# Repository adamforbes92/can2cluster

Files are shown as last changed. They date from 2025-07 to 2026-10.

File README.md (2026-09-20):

# Can2Cluster
Can2Cluster is designed to take CAN messages and convert them into an analog output for use on clusters with traditional pull-down style inputs.  It is geared towards VAG CAN messages but Ford and Emerald ECUs CAN IDs have been added too.

The code is based for an ESP32 DevKit V1, and will capture incoming CAN messages and convert them into useable 'analog' signals - like RPM, Speed, Engine Management Light (EML), Electronic Pedal Control Light (EPC) and Reverse (from DSG).  A full breakdown is below.  

Alternative setups and CAN IDs can be added and would allow custom features.

DSG gearboxes are supported and speed is currently calculated using the current gear value and RPM.  KWP2000 / UDS has been implemented and awaits testing!

On MQB vehicles, pressing the DSG Paddle +/- inputs is relayed onto the CAN bus as the real shifter/paddle module's own frame (`0x0AF`), reverse-engineered directly from a live shifter capture rather than a generic aftermarket emulation - so it lands on the bus exactly as the factory paddles would.

If no speed is available (from either hall or CAN), an optional GPS module (like the Neo6M) can be used to capture speed via. GPS.  This can be broadcast via. CAN if required - users should know the ID they would like it broadcast to.  A reminder that GPS modules need to see the sky and depending on installation location may need an external aerial to be fitted.  It uses a standard SMA connector.

WiFi calibration is supported to minimise code editting and provides valueable feedback on incoming messages.  It is viewable on 192.168.1.1 and is available for 60 seconds after boot.  If no devices connect, the WiFi will power-down automatically to reduce power consumption and heat generated by the unit.

**There is a difference in pin-out between Version 1 and Version 2 PCBs - although functionality is the same.  Confirm pinouts using the 'Module Pinout' table.**

This can be expanded to support other marques and is actively encouraged.  Other users are actively using the DSG support and using the EML/EPC outputs to configure shift locks and other features.

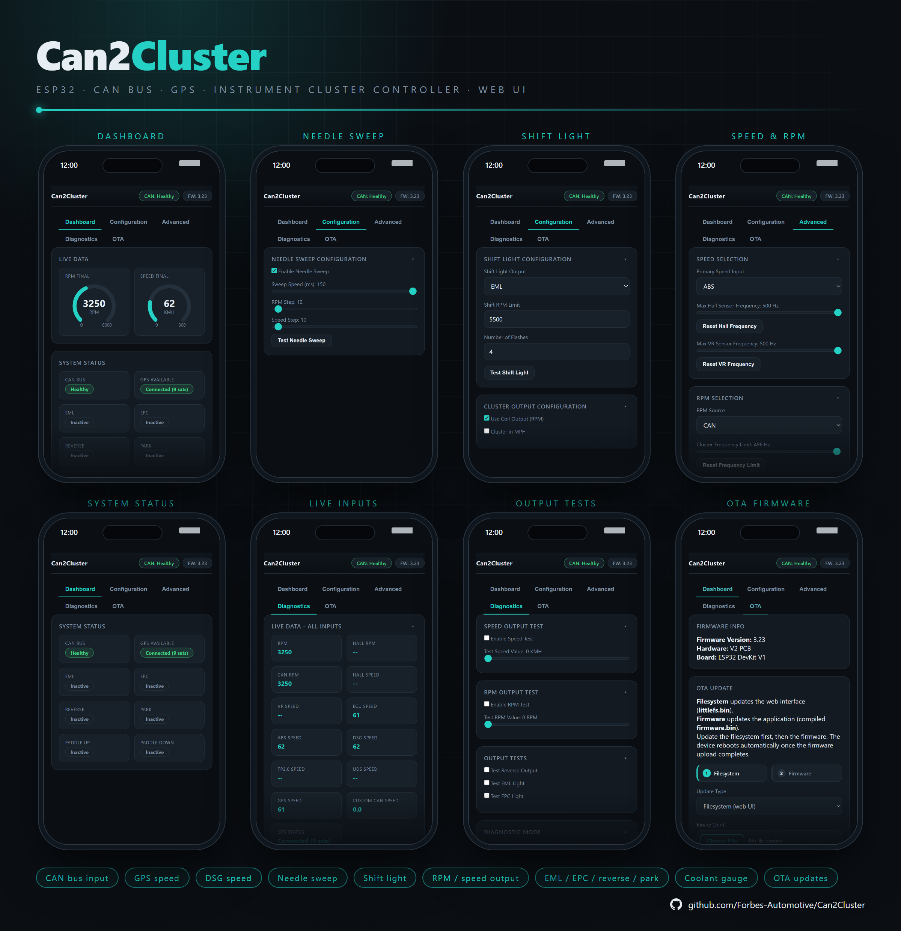
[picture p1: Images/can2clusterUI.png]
Can2Cluster Web UI — dashboard, needle sweep, shift light, speed & RPM sources, status, live inputs, output tests and OTA


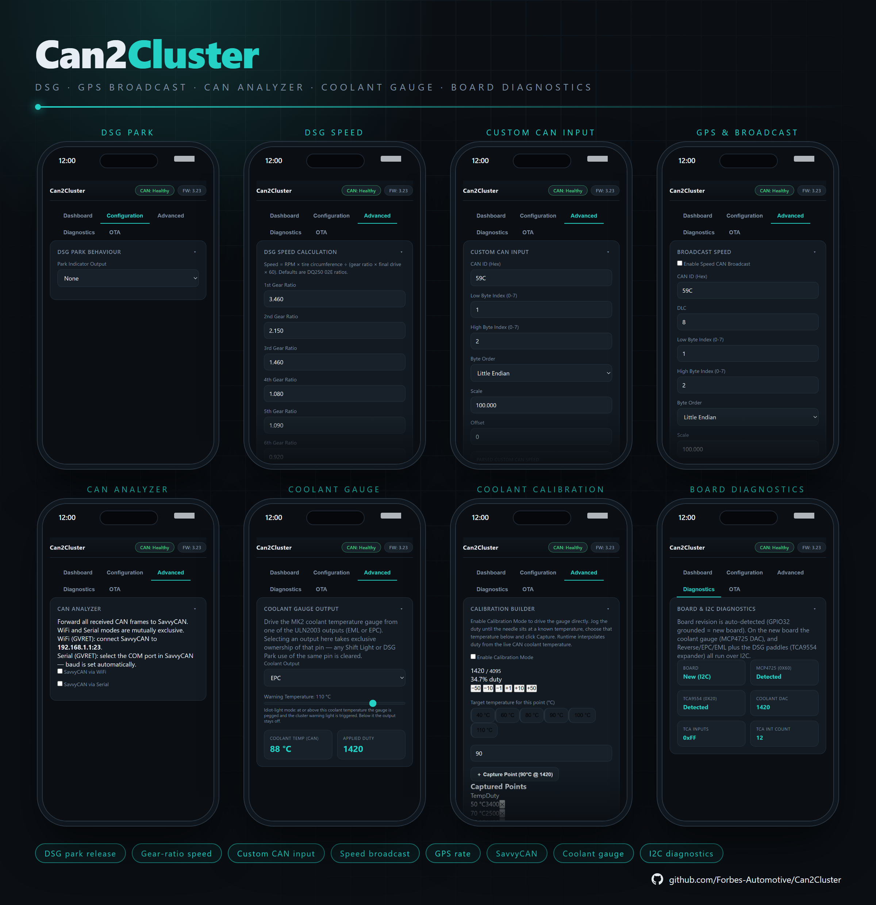
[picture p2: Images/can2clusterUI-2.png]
Can2Cluster Web UI — DSG park and speed calculation, custom CAN input, GPS & speed broadcast, CAN analyzer, coolant gauge and board diagnostics


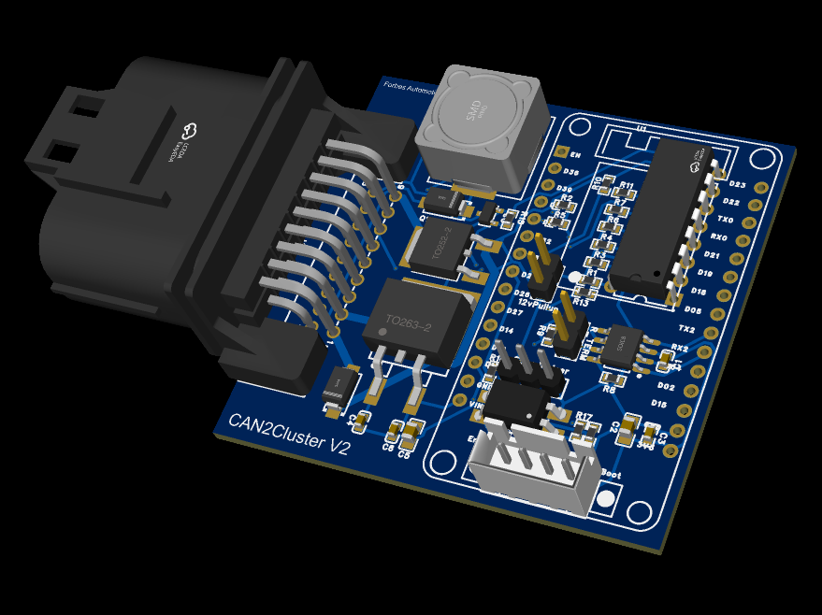
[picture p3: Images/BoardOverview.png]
Board Overview


### Purchase
If you want to purchase an assembled Can2Cluster, you can do so here: [Can2Cluster - Forbes Automotive](https://forbes-automotive.com/products/can2cluster)

## IO
Can2Cluster uses an 18-pin MX23A18 connector and features the following IO:

#### IO List
| Type | Signal | Notes |
|-----|---|---|
| Input | CAN (High & Low) | CANBUS |
| Input | DSG Paddle + | Ground to activate |
| Input | DSG Paddle - | Ground to activate |
| Input | Hall Speed | Pull-up/down options |
| Input | Hall RPM | Pull-down ONLY |
| Input | GPS | Neo6M or similar |
| Output | RPM (MK1/MK2) | High voltage 'coil type' |
| Output | RPM Square | Pull-down ONLY |
| Output | Speed Square | Pull-down ONLY |
| Output | EML & EPC | Pull-down ONLY |
| 11 | Reverse | 5A high-side |

#### Optional / Cool Features 
Shift Light (RPM vs. EML/EPC)
Needle Sweep
Park release for DSG

### Pinout
The MX23A18 connector pinout is:
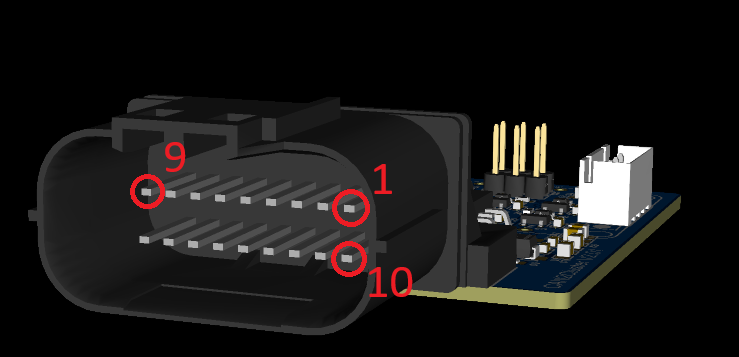
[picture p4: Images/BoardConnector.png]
Board Overview


| Pin/ | Signal | Notes |
|-----|---|---|
| 1 | Vign | 12V Ignition |
| 2 | Ground | Chassis ground — |
| 3 | Chassis CAN Low | to Chassis/ECU side |
| 4 | Chassis CAN High | to Chassis/ECU side |
| 5 | Speed | Speed output; pull-down |
| 6 | RPM | RPM output; pull-down |
| 7 | EML | Engine Management Light; pull-down |
| 8 | EPC | Electronic Pedal Control Light; pull-down |
| 9 | Reverse | 12v high-side reverse output; 5A max |
| 10 | Paddle Up | For DSG; pull-down |
| 11 | Paddle Down | For DSG; pull-down |
| 12 | Hall Speed | Optional pull-up/down |
| 13 | N/A | Not used |
| 14 | N/A | Not used |
| 15 | N/A | Not used |
| 16 | N/A | Not used |
| 17 | N/A | Not used |
| 18 | RPM | High voltage coil pulse; MK1/MK2 etc |

> **Legacy clusters & needle jitter:** On some older cluster, the coil-style RPM output can induce a little jitter in the hall inputs due to poor grounding. Fitting a **~500 Ω resistor in series** with the RPM output largely reduces this.

## Setup
Purchased modules will come pre-loaded with the most recent firmware, check back here for updates.  

> Connect the module as per the wiring diagram

> On initial power up, WiFi is available and will remain active while any client is connected. Once the last client disconnects, the radio turns off automatically after 1 minute to save power (see Power Management below).

> Connect to the device and search for '192.168.1.1' in a browser

> Configure the device to suit: Needle Sweep, Sweep Rate, RPM Type, Shift Light

> Use the 'IO' tab to confirm incoming data

### WiFi Setup
Connect to the **`Can2Cluster`** access point (open network, `192.168.1.1`) and browse to **192.168.1.1** or **c2c.local**. The Web UI is built on Forbes Automotive's shared dark theme, the same look used across OpenHaldex, SpeedPulser, SpeedPulserPro, can2rpm, the MQB Steering Wheel Controller and AirLift Controller. Current firmware version: **3.23**.

Multiple options are available in WiFi:
> Needle Sweep (rate adjustable)

> RPM Output Selection

> Shift light outputs (EML/EPC or both)

> Park Lock Release (for DSG)

> Speed Selection (Hall/ECU/ABS/DSG/GPS)

<p align="center">
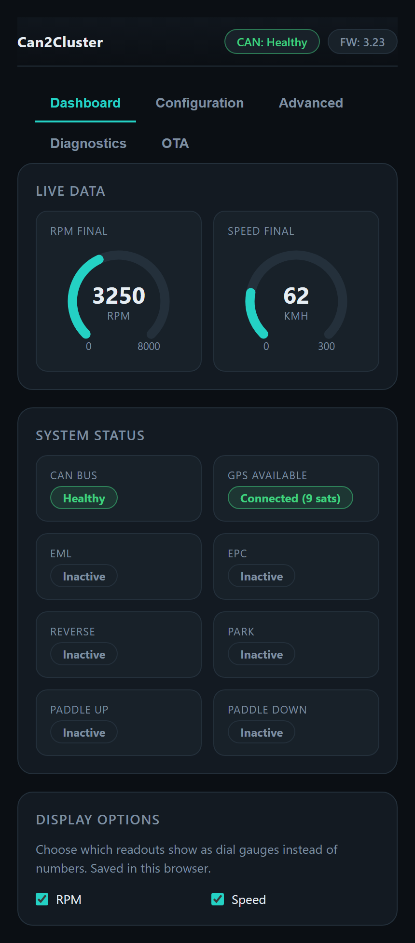
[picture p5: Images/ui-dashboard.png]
Dashboard — RPM and speed gauges, system status pills and display options
  
  &nbsp;&nbsp;
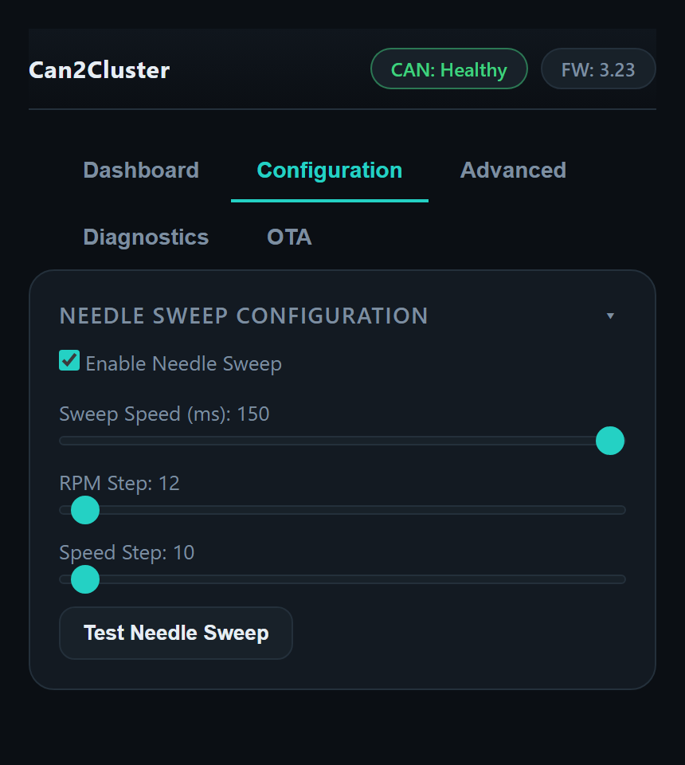
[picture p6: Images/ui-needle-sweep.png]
Configuration — needle sweep enable, sweep speed and RPM / speed step
  
</p>
<p align="center">
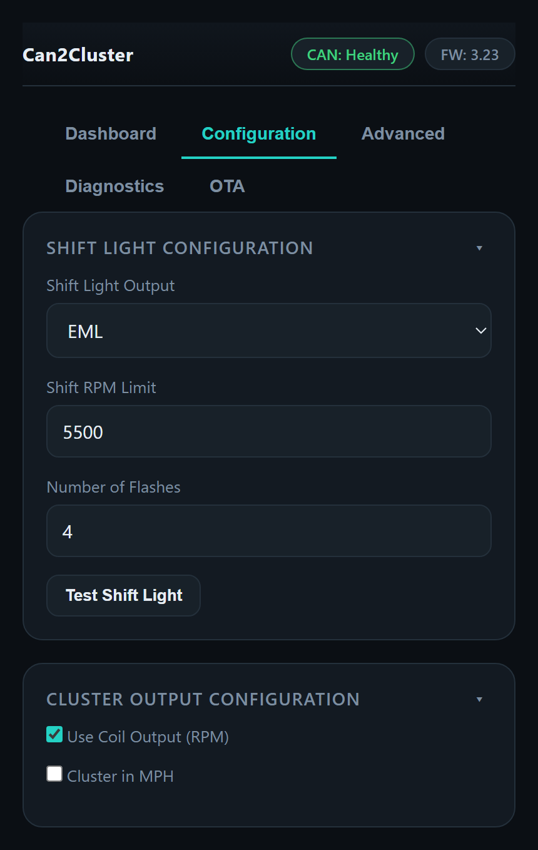
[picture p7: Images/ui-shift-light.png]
Configuration — shift light output, RPM limit and flashes; cluster output coil / MPH options
  
  &nbsp;&nbsp;
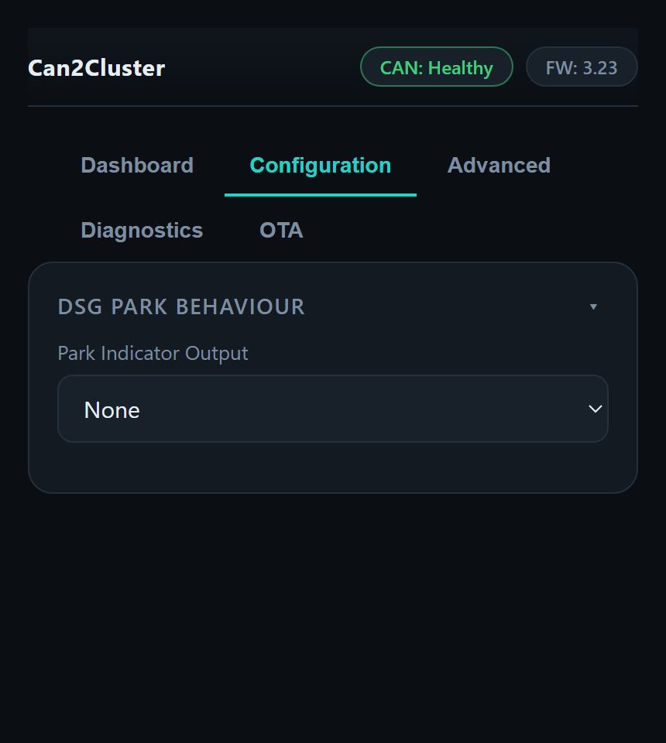
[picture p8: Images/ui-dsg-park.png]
Configuration — DSG park behaviour (park indicator output)
  
</p>
<p align="center">
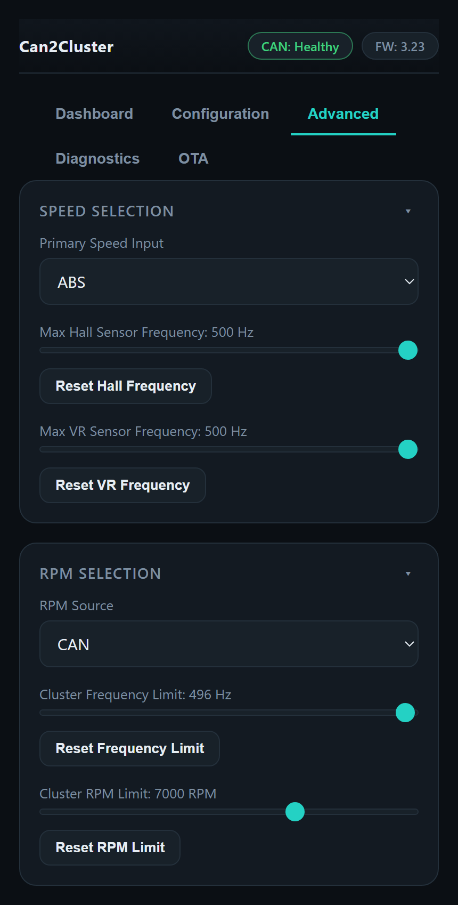
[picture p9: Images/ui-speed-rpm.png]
Advanced — speed and RPM source selection with hall / VR frequency limits
  
  &nbsp;&nbsp;
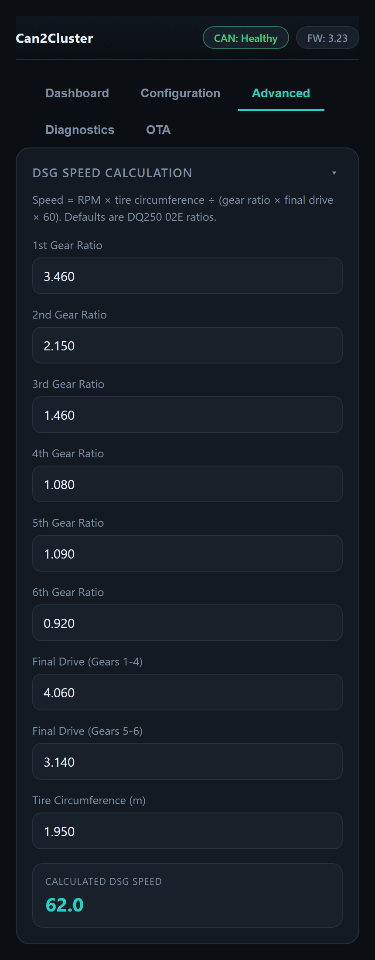
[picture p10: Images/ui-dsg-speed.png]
Advanced — DSG speed calculation: gear ratios, final drives and tyre circumference
  
</p>

*Dashboard with the final RPM/speed as dial gauges and the status pills; needle sweep, shift light, cluster output and DSG park release on the Configuration tab; speed and RPM source selection under Advanced. Choosing **DSG** as the speed source reveals the gear-ratio calculator (speed = RPM × tyre circumference ÷ gear ratio × final drive).*

**Status indicators:** CAN health, GPS and output (EML/EPC/Reverse) status are shown as coloured pills in the Web UI:

| Colour | Meaning |
|---|---|
| 🟢 Green | Healthy / active — CAN bus is healthy, GPS has a satellite lock, or the output reflects a real vehicle CAN signal |
| 🔴 Red | Unhealthy / not available — CAN bus unhealthy, or no GPS module fitted/connected |
| 🟠 Orange | A caveat, not a failure — GPS module is connected but has no satellite fix yet ("Connected (no sats)"), or an EML/EPC/Reverse output is being **forced on via the built-in test/diagnostic mode** rather than a real vehicle signal |

<p align="center">
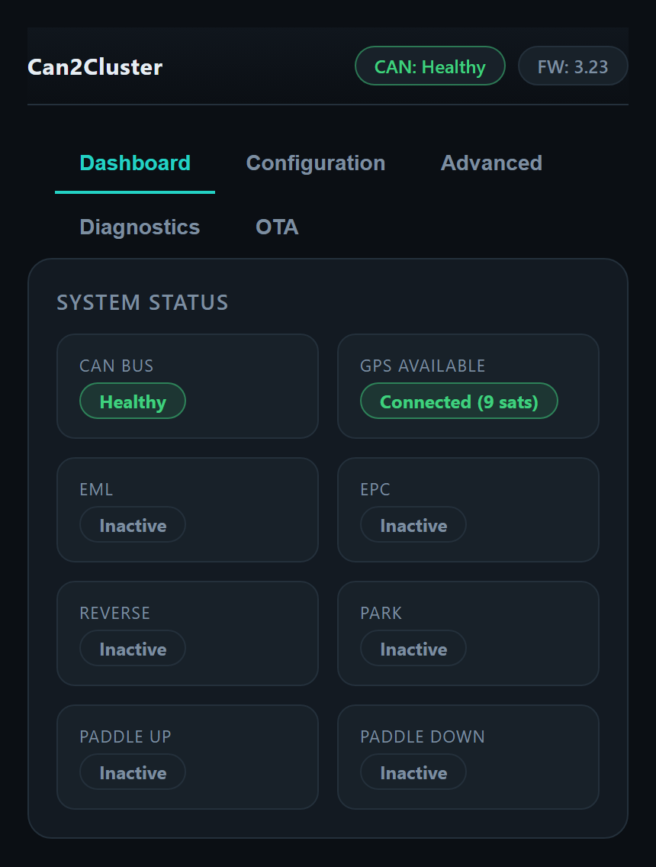
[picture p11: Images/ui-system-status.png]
Dashboard — system status pills: CAN bus, GPS, EML, EPC, reverse, park, paddles
  
</p>

## Adding CAN Functionality
Users wishing to add CAN functionality not available are encourged to push commits to the project.  The main section of code for managing imcoming CAN messages are handled in an interrupt and corresponding outputs are pushed automatically.  Users should know the CAN ID and Bytes they wish to process and what variables to assign them to.

Two things in the Web UI help here. **CAN Analyzer** (Advanced tab) forwards every received frame to [SavvyCAN](https://www.savvycan.com/) over WiFi (GVRET, `192.168.1.1:23`) or over the USB serial port, so you can find the ID and bytes you're after. And for a speed signal on a non-standard ID, **Custom CAN Input** (choose *Custom* as the speed source) lets you enter the CAN ID, byte positions, byte order, scale and offset without touching the code:

<p align="center">
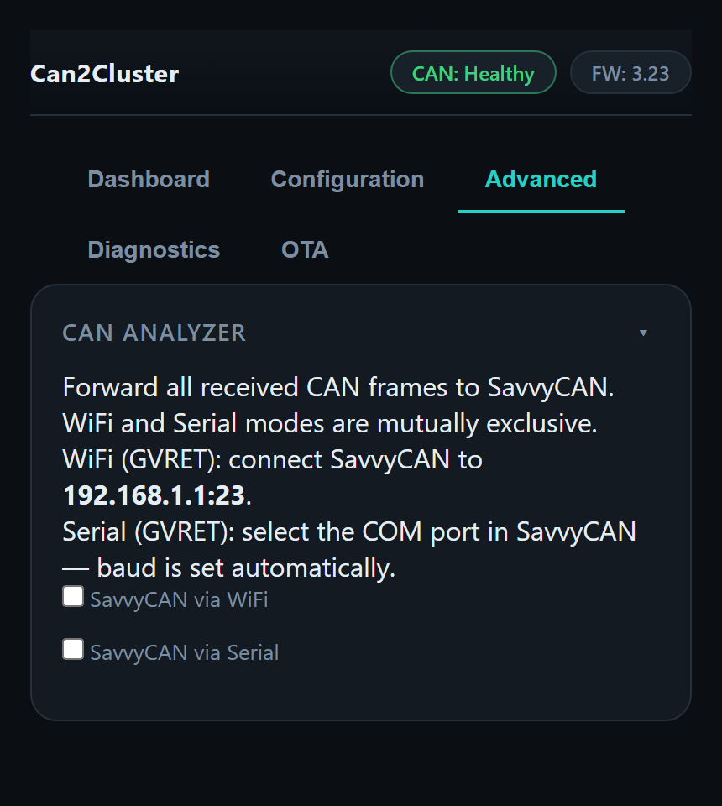
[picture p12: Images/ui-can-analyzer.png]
Advanced — CAN Analyzer: forward frames to SavvyCAN over WiFi or serial
  
  &nbsp;&nbsp;
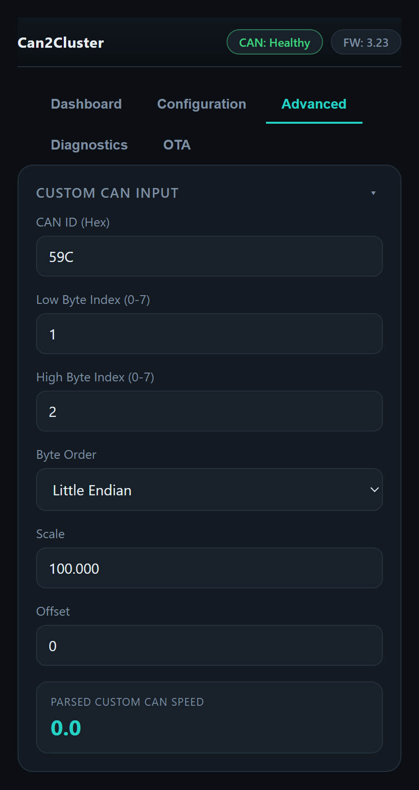
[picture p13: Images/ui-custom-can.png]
Advanced — Custom CAN Input: CAN ID, byte indexes, byte order, scale and offset, with the parsed speed shown live
  
</p>

For example (in _CAN.ino under "onBodyRX");
```
    case emeraldECU1_ID:
      vehicleRPM = ((frame.buf[0] << 8) | frame.buf[1]);  // conversion: 0.25*HEX // this is RPM
      break;

    case emeraldECU2_ID:
      vehicleSpeed = ((frame.buf[2] << 8) | frame.buf[3]) * (2.25 / 256);  // conversion: 0.25*HEX // this is RPM
      break;

```
The above entry will check to see if there is a CAN message from "0x1000" or "0x1001" (Emerald ECU 1 & 2) and then parse the data to the relevant variables.

## Adding GPS
Users wishing to add GPS at a future date can do - the boards are already socketed in readiness.  The 4-pin JST XH Connector will provide 3.3v, RX, TX and ground.

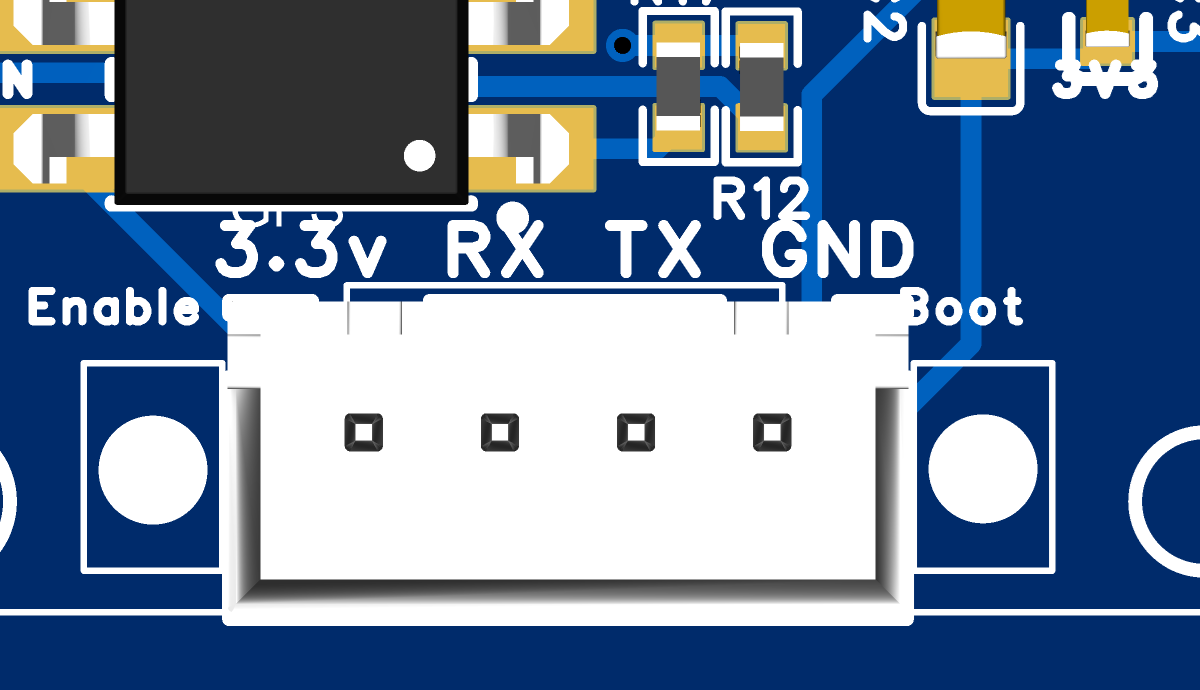
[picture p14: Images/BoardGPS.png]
GPS Connection


Once fitted, pick **GPS** as the speed source on the Advanced tab. The same tab sets the receiver's **update rate** and, if another module on the bus needs the speed, **Broadcast Speed** puts it onto CAN on an ID, byte layout and scale of your choosing:

<p align="center">
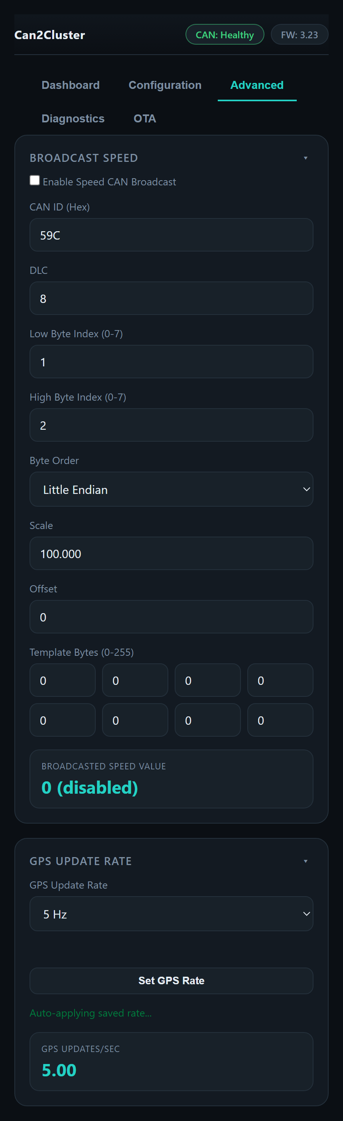
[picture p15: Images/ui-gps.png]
Advanced — Broadcast Speed (CAN ID, DLC, byte layout, scale) and GPS Update Rate
  
</p>

## Hall & RPM Input Parsing
When speed or RPM is taken from the hall/VR/pulse inputs (rather than CAN), the frequency is measured within a **windowed capture** rather than a single edge-to-edge period. Each interrupt accumulates the edge intervals and a count, and the task averages them once per loop (`frequency = intervals ÷ summed interval time`) — which gives a true average over a period.

This matters because a single-period reading turns tone-wheel / tooth-spacing jitter straight into a jumpy needle. Pulses that are arriving closer than ~3 ms (> 333 Hz) are rejected as electrical noise, so electrical or ignition-coil EMI on the input can't be mistaken for a valid speed or RPM. The averaged frequency is then mapped to the cluster scale (`map(frequency, 0, maxFreqHall/maxRPM, 0, maxSpeed/clusterRPMLimit)`).

Every input the module can see is listed side by side on the **Diagnostics** tab, so it is obvious which sources are live before choosing one, and the output tests drive the cluster directly from the page:

<p align="center">
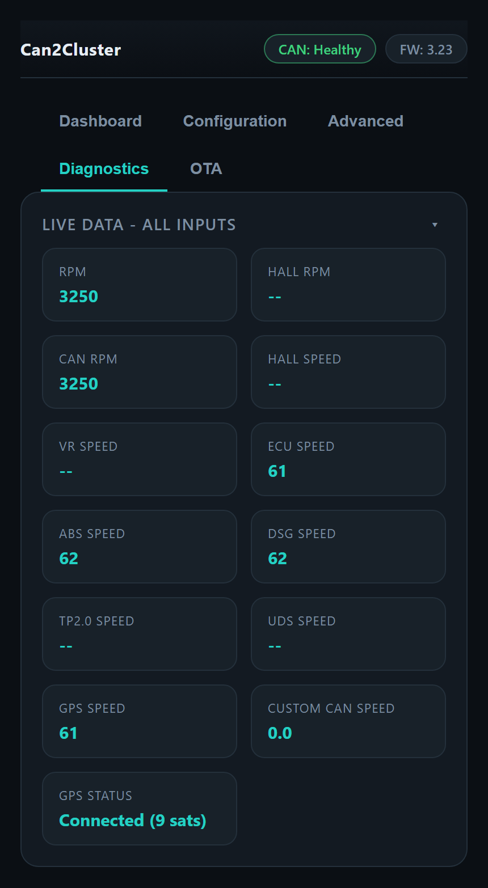
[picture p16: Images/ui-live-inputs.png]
Diagnostics — live data from every input: RPM, hall, CAN, VR, ECU, ABS, DSG, TP2.0, UDS, GPS and custom CAN speed
  
  &nbsp;&nbsp;
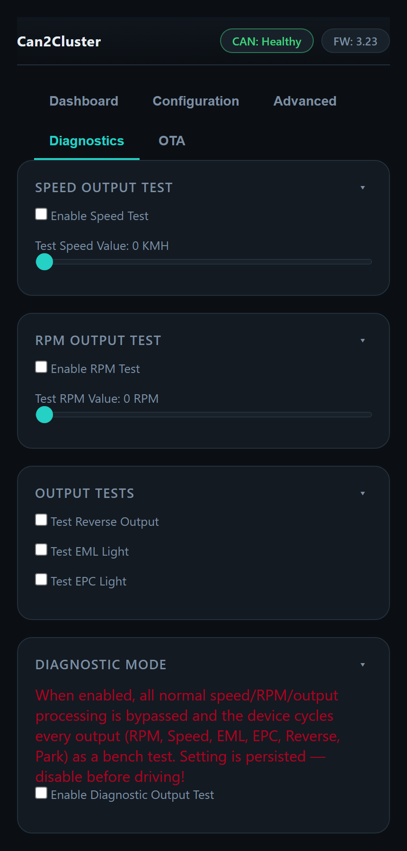
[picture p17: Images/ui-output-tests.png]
Diagnostics — speed and RPM output tests, EML / EPC / reverse output tests and diagnostic mode
  
</p>

*Diagnostics: every speed and RPM source side by side (left); slider-driven speed and RPM output tests, the EML / EPC / reverse output tests and the diagnostic (forced-output) mode that shows as orange pills on the dashboard (right).*

The Diagnostics tab also reports which board revision was detected and whether the I2C peripherals on the V2 PCB (the coolant DAC and the port expander that drives Reverse / EPC / EML and reads the DSG paddles) answered:

<p align="center">
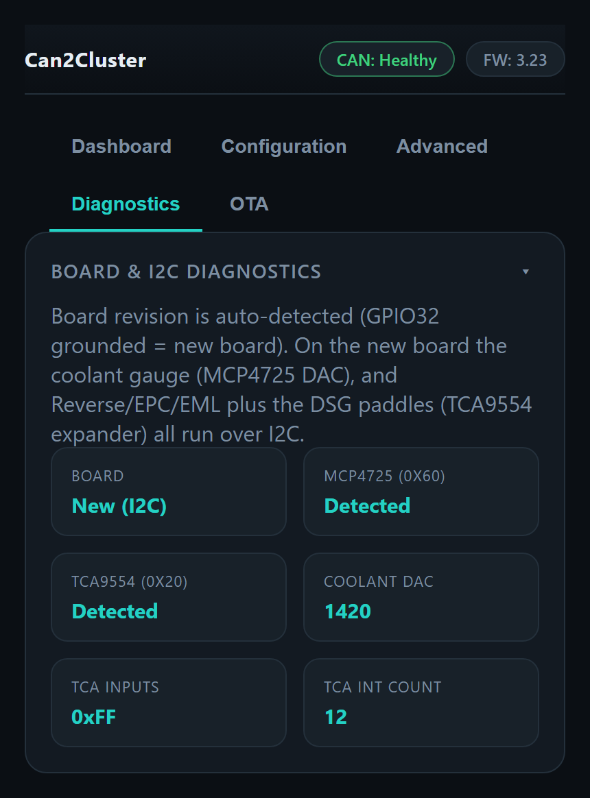
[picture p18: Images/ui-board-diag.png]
Diagnostics — Board & I2C diagnostics: board revision, MCP4725 DAC, TCA9554 expander, coolant DAC value
  
</p>

## Coolant Gauge Output
On the V2 PCB the MK2-style coolant temperature gauge can be driven from the CAN coolant temperature through one of the ULN2003 outputs (EML or EPC — selecting one takes that pin away from the shift light / DSG park use). Above the **warning temperature** the gauge is pegged and the cluster warning light is triggered.

Because every gauge is different, the **Calibration Builder** lets you drive the needle directly: enable calibration mode, jog the duty until the needle sits on a known mark, pick that temperature and **Capture**. The stored points are drawn as a curve and interpolated at runtime.

<p align="center">
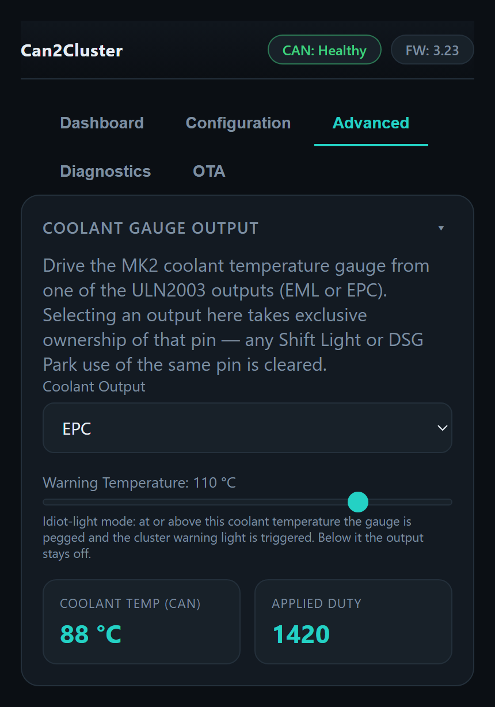
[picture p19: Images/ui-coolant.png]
Advanced — Coolant Gauge Output: output pin, warning temperature, live coolant temperature and applied duty
  
  &nbsp;&nbsp;
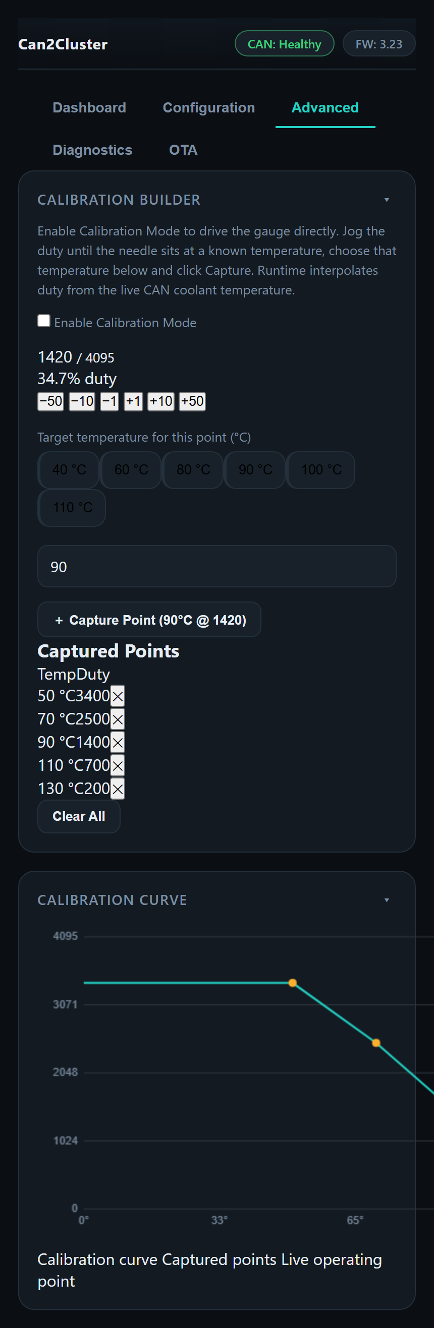
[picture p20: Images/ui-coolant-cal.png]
Advanced — Calibration Builder with duty jog buttons, captured points and the resulting calibration curve
  
</p>

## Jumpers
To keep functionality, there are a variety of jumpers available on the board which can be added/removed to suit the chassis.

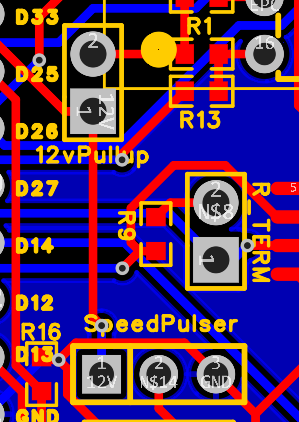
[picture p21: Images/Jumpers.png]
Jumpers


### R-Term
The jumper marked 'r-term' is the terminating resistor for the CANBUS network.  If there are no other CAN devices on the network (this is the only one), the jumper should remain.  If there are other devices on the network, this can be removed.

### SpeedPulser
A selector for a hall sensor can be configured as pull-up or pull-down with the central pin being the hall sensor itself.  Typically, VAG ones are 'pull-up'.

### 12v Pullup
Used to configure outputs if the cluster does not have internal pull-ups.

### Over-the-Air Updates (Two-Step)
OTA is enabled, so updating to the latest release is seamless and doesn't require removing the module from the vehicle. Firmware and the web UI live on separate flash partitions, so an update is done in **two steps** from the OTA tab:

1. **Filesystem** — upload `littlefs.bin` (`POST /api/ota/fs`, written to the SPIFFS partition). Updates the web UI (`index.html`, `app.js`, `style.css`). The device does **not** reboot after this step.
2. **Firmware** — upload `firmware.bin` (`POST /api/ota`, written to the OTA app partition). Updates the application and reboots automatically once complete.

`GET /api/ota/info` reports the running version, board and hardware.

> Download the most recent 'Release' - this will be saved locally on your phone/laptop/etc as `.bin` file(s)

> Connect to Can2Cluster on WiFi (or browse to c2c.local)

> Go to 192.168.1.1 and choose the OTA tab

> Upload the filesystem image first, then the firmware image

> Wait for the ESP to reboot after the firmware step

<p align="center">
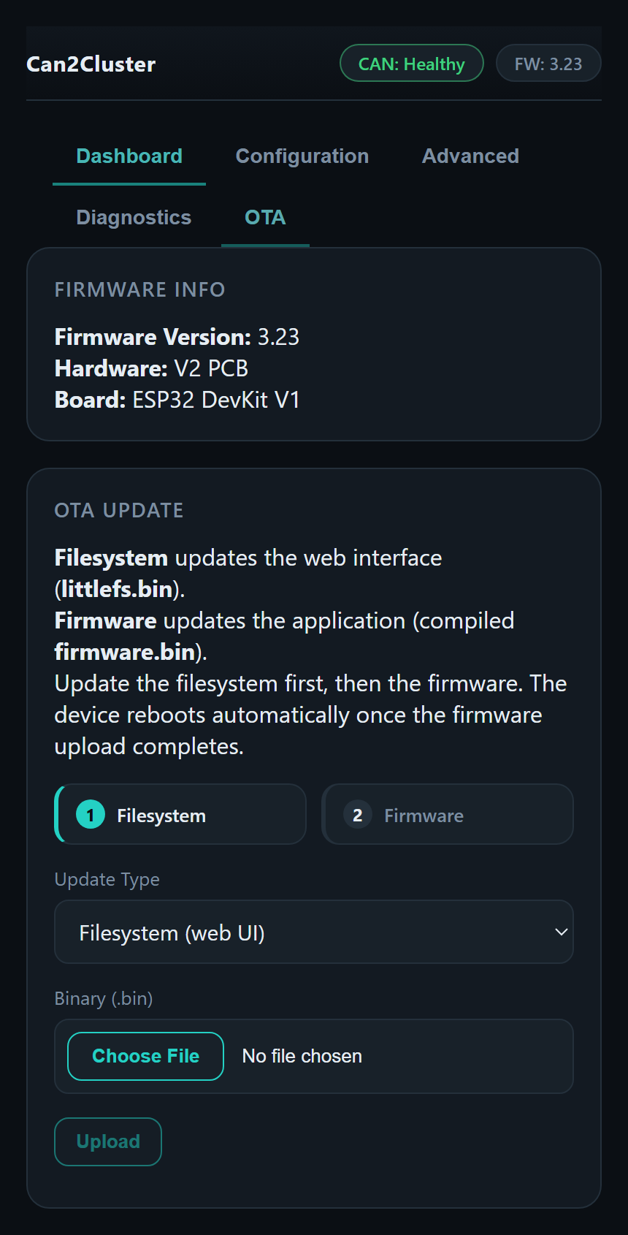
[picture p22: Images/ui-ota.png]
OTA tab — firmware info and two-step update
  
</p>

## Power Management
The firmware includes a universal reduced-power module that automatically saves current once no clients are connected to the WiFi AP. This directly reduces heat generated by the on-board linear voltage regulator — a linear regulator dissipates heat proportional to `(Vin − Vout) × I_load`, so every milliamp saved is less heat.

**What happens 1 minute after the last client disconnects:**
> WiFi radio off — the single biggest saving (~80–120 mA average)

> CPU frequency scaled: 240 MHz → 80 MHz

> Bluetooth controller disabled at boot (frees ~60 KB RAM)

> Onboard LED off at boot

Everything restores automatically the moment a client reconnects. A power-cycle (ignition off/on) will also bring WiFi back if required.

## PCB Design
The PCB has been designed in EasyEDA and available in the 'PCB' folder.

## PCB Principles
The board is based around an ESP32 with an external CAN chip (SN65HVD230) with an optional termination resistor (if there are no other CAN devices on the network). 

The outputs are controlled via. a ULN2003A (a 200mA 7-channel Darlington Array) which is socketed so that if damaged can be swapped out.  This array is used to trigger each of the outputs - including the high-side 5A MOSFET (for reverse light, typically).

GPS is captured via. a Neo6M module and via. a Software Serial connection.  It is supplied with an external aerial - although there may be a requirement to add a cabled external aerial.  The connector is a standard SMA connector.  

The aerial that can be found on Google with a search "sma gps antenna".

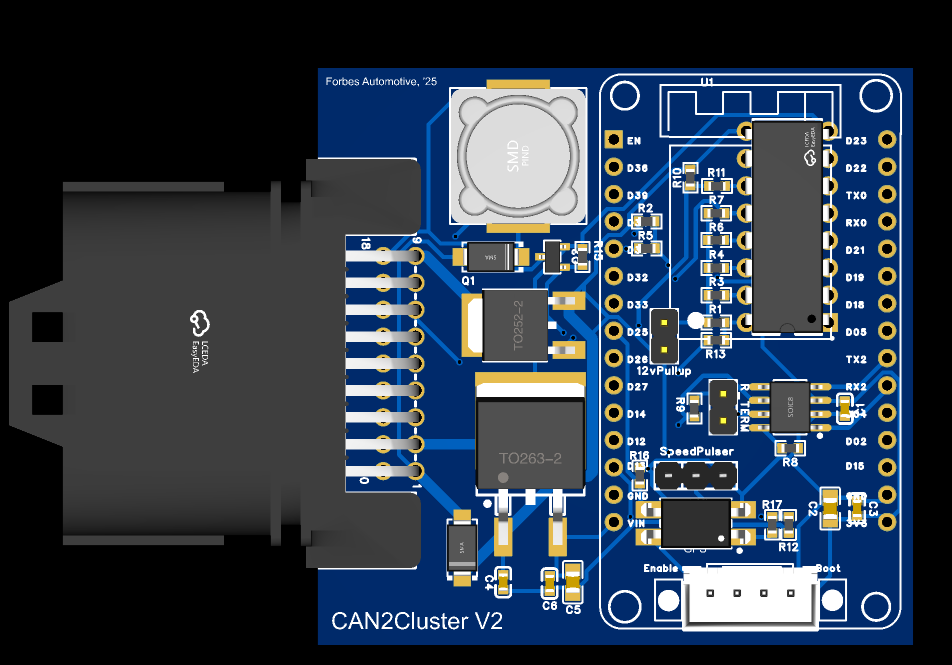
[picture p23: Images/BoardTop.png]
Board Top


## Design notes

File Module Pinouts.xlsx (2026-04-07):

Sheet: V1
Pin Number | Basic Detail | Comments
1 | 12v Ignition (K15) | Switched power (for waking up the module)
2 | Reverse | Via. Internal relay - 3A max. - for DSG
3 | Ground | Module ground - to chassis etc
4 | N/A | Not used
5 | CAN L | CAN Low from ECU
6 | N/A | Not used
7 | CAN H | CAN High from ECU
8 | Paddle down | Steering wheel paddle down - input to ground - for DSG
9 | N/A | Not used
10 | Paddle up | Steering wheel paddle up - input to ground - for DSG
11 | N/A | Not used
12 | EPC | 12v to EPC
13 | N/A | Not used
14 | EML | 12v to EML
15 | N/A | Not used
16 | RPM | 12v to cluster RPM (>MK2 / not high voltage)
17 | RPM | MK1 / MK2 to cluster RPM (high voltage!)
18 | Speed | 12v pulsed speed

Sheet: V2
Pin Number | Basic Detail | Comments
1 | 12v Ignition (K15) | Switched power (for waking up the module)
2 | Ground | Chassis ground
3 | CAN L | Powertrain CAN Low
4 | CAN H | Powertrain CAN High
5 | Speed | 12v - pull-to-ground pulsed speed
6 | RPM | 12v - pull-to-ground pulsed rpm
7 | EML | 12v - pull-to-ground pulsed engine management light (EML) light
8 | EPC | 12v - pull-to-ground pulsed electronic pedal control (EPC) light
9 | Reverse | 5A MAX. reverse output (signalled from DSG CAN)
10 | Paddle up | Steering wheel paddle up - input to ground - for DSG
11 | Paddle down | Steering wheel paddle down - input to ground - for DSG
12 | Hall Speed | Hall sensor input - can broadcast over CAN if required
13 | N/A | Not used
14 | N/A | Not used
15 | N/A | Not used
16 | N/A | Not used
17 | N/A | Not used
18 | RPM | High voltage coil pulse - for MK1/MK2 etc

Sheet: Mini
Pin Number | Basic Detail | Comments
1 | 12v Ignition (K15) | Switched power (for waking up the module)
2 | Ground | Chassis ground
3 | CAN L | Powertrain CAN Low
4 | CAN H | Powertrain CAN High
5 | Paddle up | Steering wheel paddle up - input to ground - for DSG
6 | Paddle down | Steering wheel paddle down - input to ground - for DSG
7 | Speed | 12v - pull-to-ground pulsed speed output
8 | RPM | 12v - pull-to-ground pulsed RPM output
9 | EML | 12v - pull-to-ground Engine Management Light
10 | EPC | 12v - pull-to-ground Electronic Pedal Control Light
11 | Reverse | 5A MAX. reverse output (signalled from DSG CAN)
12 | N/A | Not used

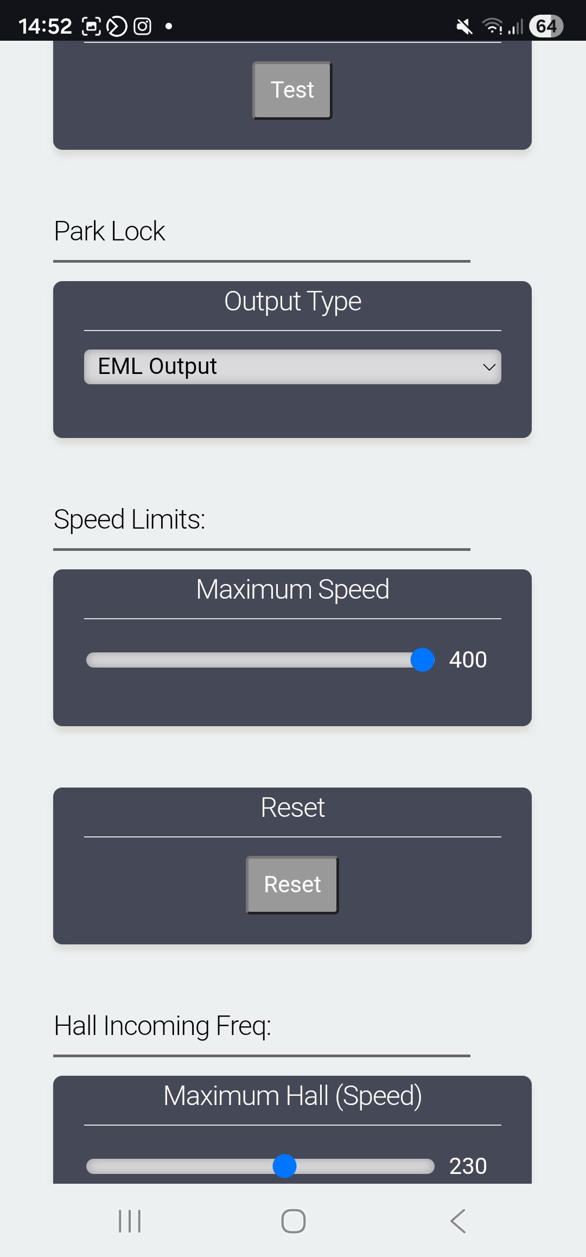
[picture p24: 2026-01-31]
Images/WiFi5.jpg

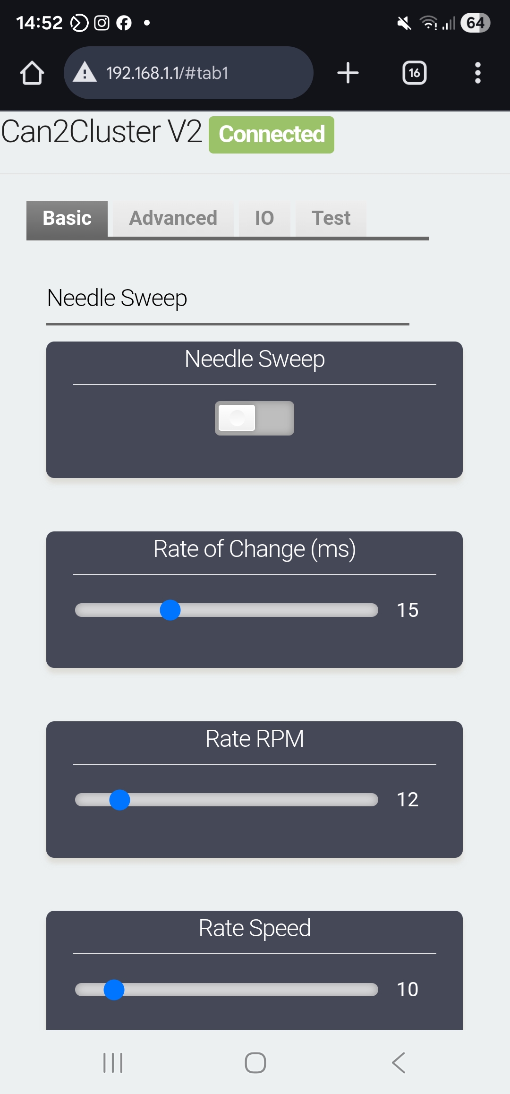
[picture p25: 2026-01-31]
Images/WiFi1.jpg

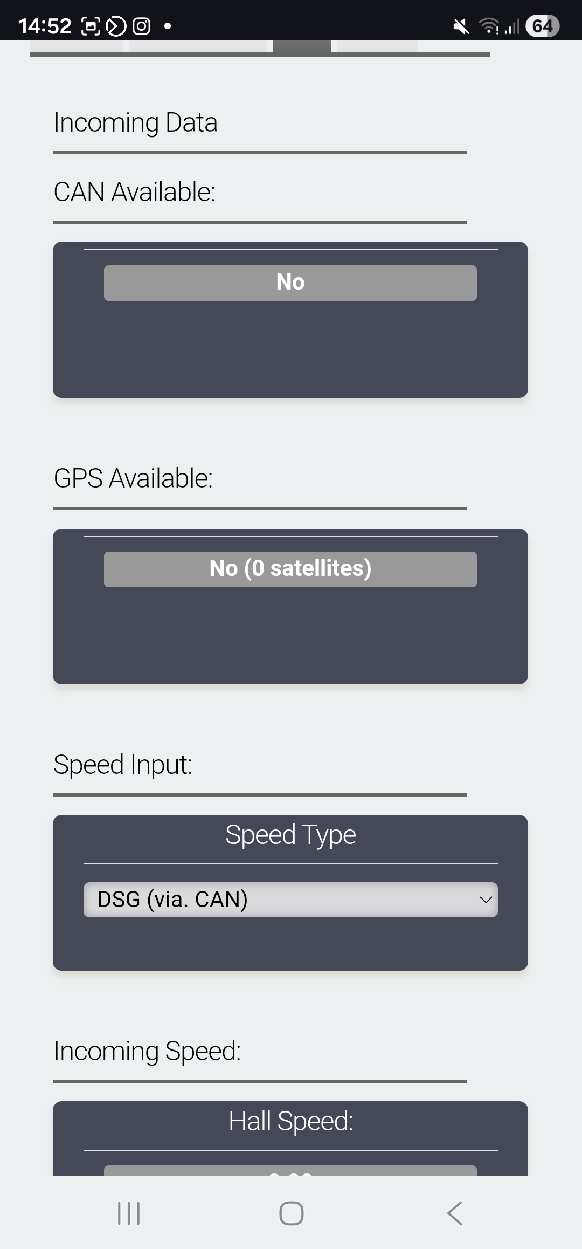
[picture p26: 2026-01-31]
Images/WiFi6.jpg

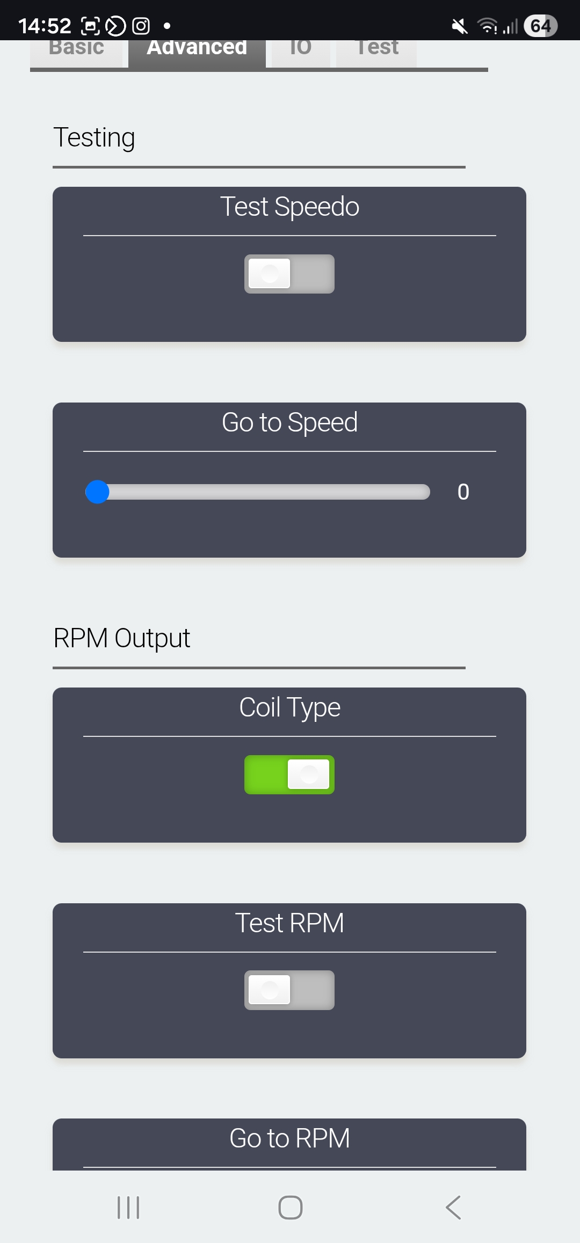
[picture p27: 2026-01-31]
Images/WiFi2.jpg

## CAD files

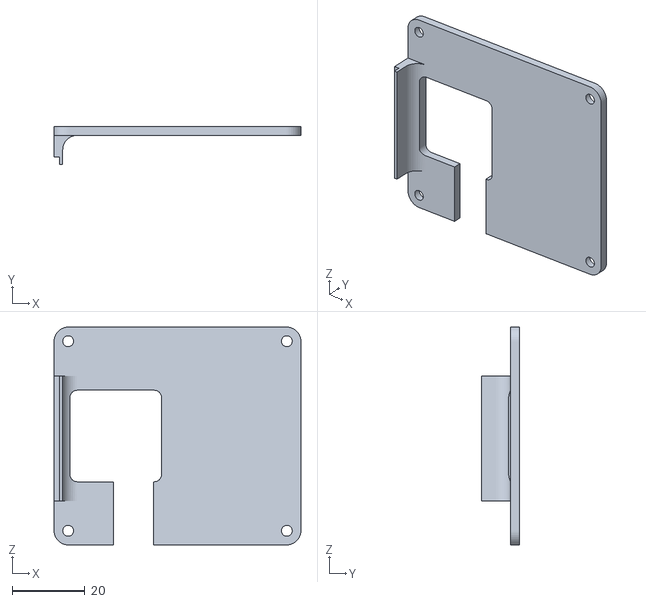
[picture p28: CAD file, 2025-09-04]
Enclosure/Can2ClusterV2LidGPS.STL
68.0 x 10.4 x 60.0

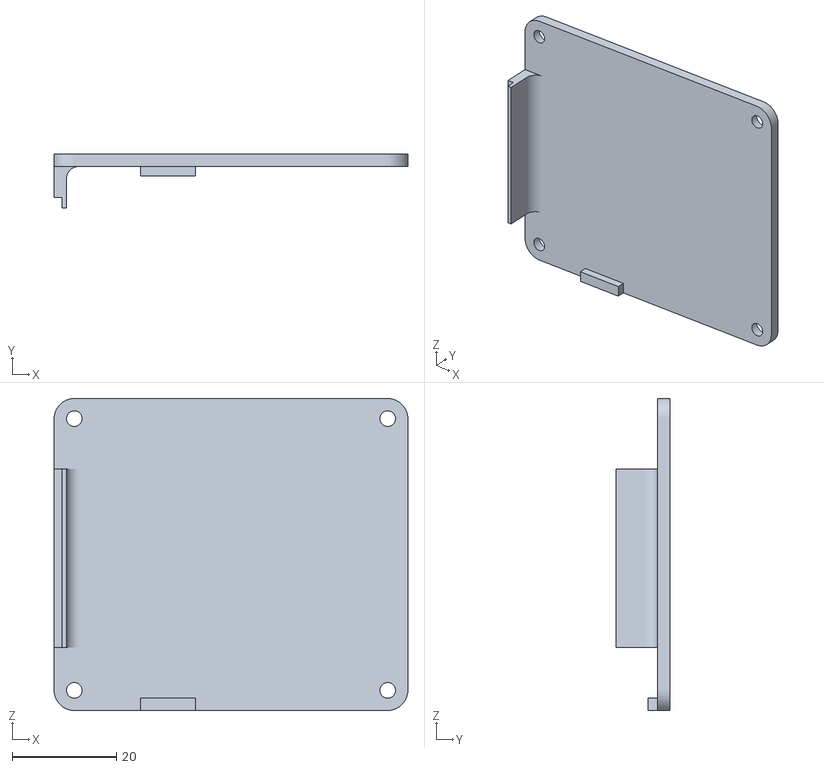
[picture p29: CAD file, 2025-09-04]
Enclosure/Can2ClusterV2LidNoGPS.STL
68.0 x 10.4 x 60.0

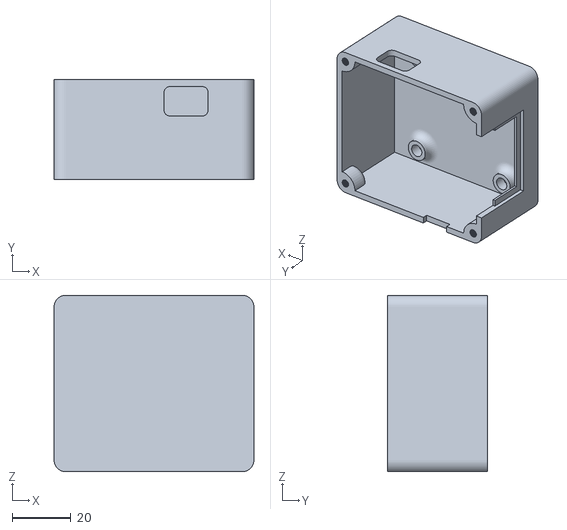
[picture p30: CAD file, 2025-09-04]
Enclosure/Can2ClusterV2.STL
68.0 x 34.0 x 60.0

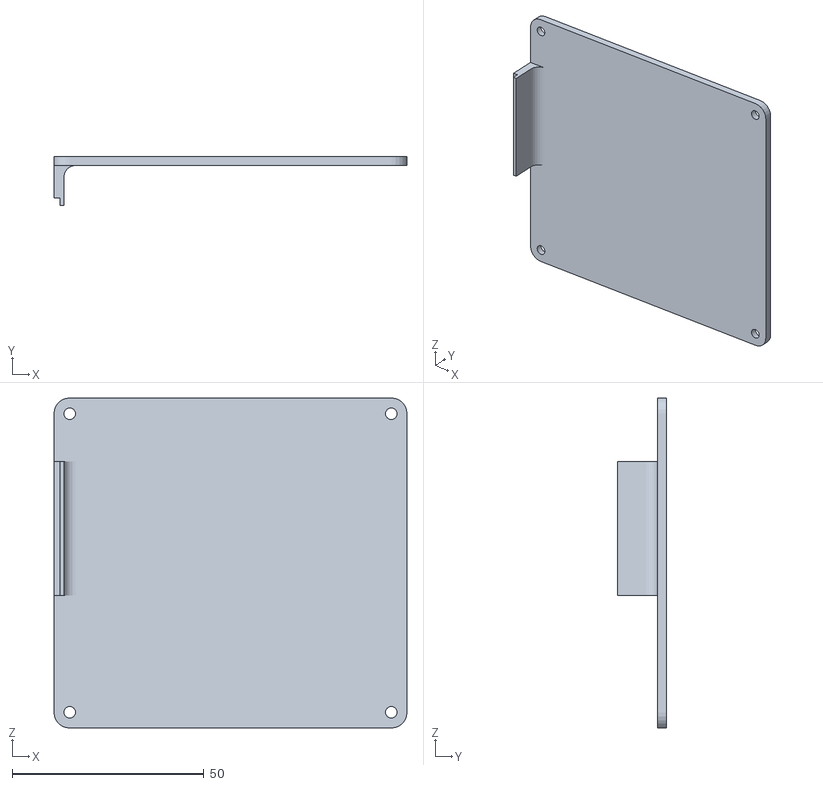
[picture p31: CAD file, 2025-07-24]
Enclosure/Can2ClusterLid.STL
92.0 x 12.9 x 86.0

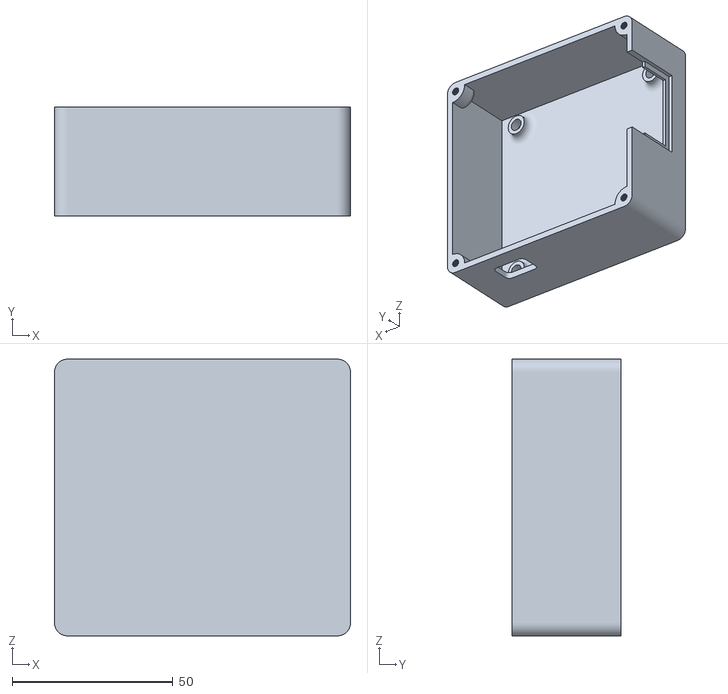
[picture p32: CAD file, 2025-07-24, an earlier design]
Enclosure/Can2Cluster.STL
92.0 x 34.0 x 86.0

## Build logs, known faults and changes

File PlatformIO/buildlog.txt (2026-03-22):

C:\.platformio\penv\Scripts\platformio.exe : 
C:\.platformio\penv\Lib\site-packages\requests\__init__.py:113: 
RequestsDependencyWarning: urllib3 (1.26.20) or chardet 
(7.2.0)/charset_normalizer (None) doesn't match a supported version!
At line:1 char:42
+ ... n2Cluster"; C:\.platformio\penv\Scripts\platformio.exe run --environm ...
+                 ~~~~~~~~~~~~~~~~~~~~~~~~~~~~~~~~~~~~~~~~~~~~~~~~~~~~~~~~~
    + CategoryInfo          : NotSpecified: (C:\.platformio\...ported version! 
   :String) [], RemoteException
    + FullyQualifiedErrorId : NativeCommandError
 
  warnings.warn(
Processing esp32doit-devkit-v1 (platform: https://github.com/pioarduino/platform-espressif32/releases/download/54.03.20/platform-espressif32.zip; board: esp32doit-devkit-v1; framework: arduino; monitor_speed: 115200; lib_deps: https://github.com/plerup/espsoftwareserial, https://github.com/mikalhart/TinyGPSPlus, https://github.com/s00500/ESPUI, https://github.com/rwmingis/InterruptButton, https://github.com/collin80/esp32_can, https://github.com/collin80/can_common, mathieucarbou/AsyncTCP@^3.1.4, mathieucarbou/ESP Async WebServer@^3.0.6, bblanchon/ArduinoJson@^7.0.0)
--------------------------------------------------------------------------------
C:\.platformio\penv\Lib\site-packages\requests\__init__.py:113: 
RequestsDependencyWarning: urllib3 (1.26.20) or chardet 
(7.2.0)/charset_normalizer (None) doesn't match a supported version!
  warnings.warn(
CONFIGURATION: https://docs.platformio.org/page/boards/espressif32/esp32doit-devkit-v1.html
PLATFORM: Espressif 32 (54.3.20) (https://github.com/pioarduino/platform-espressif32/releases/download/54.03.20/platform-espressif32.zip) > DOIT ESP32 DEVKIT V1
HARDWARE: ESP32 240MHz, 320KB RAM, 4MB Flash
DEBUG: Current (cmsis-dap) External (cmsis-dap, esp-bridge, esp-prog, iot-bus-jtag, jlink, minimodule, olimex-arm-usb-ocd, olimex-arm-usb-ocd-h, olimex-arm-usb-tiny-h, olimex-jtag-tiny, tumpa)
PACKAGES: 
 - framework-arduinoespressif32 @ 3.2.0 (https://github.com/espressif/arduino-esp32/releases/download/3.2.0/esp32-3.2.0.zip) 
 - framework-arduinoespressif32-libs @ 5.4.0+sha.2f7dcd862a (https://github.com/espressif/esp32-arduino-lib-builder/releases/download/idf-release_v5.4/esp32-arduino-libs-idf-release_v5.4-2f7dcd86-v1.zip) 
 - tool-esptoolpy @ 4.8.9 (https://github.com/pioarduino/esptool/releases/download/v4.8.9/esptool.zip) 
 - tool-mklittlefs @ 3.2.0 
 - tool-riscv32-esp-elf-gdb @ 14.2.0+20240403 
 - tool-xtensa-esp-elf-gdb @ 14.2.0+20240403 
 - toolchain-xtensa-esp-elf @ 14.2.0+20241119
LDF: Library Dependency Finder -> https://bit.ly/configure-pio-ldf
LDF Modes: Finder ~ chain, Compatibility ~ soft
Found 54 compatible libraries
Scanning dependencies...
Warning: Ignored `AsyncTCP` dependency for `ESPAsyncWebServer` library
Warning: Ignored `ESPAsyncTCP` dependency for `ESPAsyncWebServer` library
Warning: Ignored `Hash` dependency for `ESPAsyncWebServer` library
Warning: Ignored `RPAsyncTCP` dependency for `ESPAsyncWebServer` library
Warning: Ignored `ESPAsyncTCP-esphome` dependency for `ESP Async WebServer` 
library
Warning: Ignored `Hash` dependency for `ESP Async WebServer` library
Warning: Ignored `AsyncTCP_RP2040W` dependency for `ESP Async WebServer` 
library
Dependency Graph
|-- EspSoftwareSerial @ 8.2.0+sha.40038df (License: LGPL-2.1+, URI: git+https://github.com/plerup/espsoftwareserial, Path: E:\My Drive\OpenHaldex\Can2Cluster\.pio\libdeps\esp32doit-devkit-v1\EspSoftwareSerial)
|   |-- ghostl @ 1.0.1 (License: LGPL-2.1+, Path: E:\My Drive\OpenHaldex\Can2Cluster\.pio\libdeps\esp32doit-devkit-v1\ghostl)
|-- TinyGPSPlus @ 1.1.0+sha.0a20575 (License: Unknown, URI: git+https://github.com/mikalhart/TinyGPSPlus, Path: E:\My Drive\OpenHaldex\Can2Cluster\.pio\libdeps\esp32doit-devkit-v1\TinyGPSPlus)
|-- ESPUI @ 2.2.4+sha.c7b7edf (License: Unknown, URI: git+https://github.com/s00500/ESPUI, Path: E:\My Drive\OpenHaldex\Can2Cluster\.pio\libdeps\esp32doit-devkit-v1\ESPUI)
|   |-- ESPAsyncWebServer @ 3.10.3 (License: LGPL-3.0, Path: E:\My Drive\OpenHaldex\Can2Cluster\.pio\libdeps\esp32doit-devkit-v1\ESPAsyncWebServer)
|   |   |-- WiFi @ 3.2.0 (License: Unknown, Path: C:\.platformio\packages\framework-arduinoespressif32\libraries\WiFi)
|   |   |   |-- Networking @ 3.2.0 (License: Unknown, Path: C:\.platformio\packages\framework-arduinoespressif32\libraries\Network)
|   |   |-- Async TCP @ 3.1.4 (License: LGPL-3.0, Path: E:\My Drive\OpenHaldex\Can2Cluster\.pio\libdeps\esp32doit-devkit-v1\Async TCP)
|   |   |-- ArduinoJson @ 7.4.3 (License: Unknown, Path: E:\My Drive\OpenHaldex\Can2Cluster\.pio\libdeps\esp32doit-devkit-v1\ArduinoJson)
|   |   |-- FS @ 3.2.0 (License: Unknown, Path: C:\.platformio\packages\framework-arduinoespressif32\libraries\FS)
|   |-- ArduinoJson @ 7.4.3 (License: Unknown, Path: E:\My Drive\OpenHaldex\Can2Cluster\.pio\libdeps\esp32doit-devkit-v1\ArduinoJson)
|   |-- WiFi @ 3.2.0 (License: Unknown, Path: C:\.platformio\packages\framework-arduinoespressif32\libraries\WiFi)
|   |   |-- Networking @ 3.2.0 (License: Unknown, Path: C:\.platformio\packages\framework-arduinoespressif32\libraries\Network)
|   |-- ArduinoOTA @ 3.2.0 (License: Unknown, Path: C:\.platformio\packages\framework-arduinoespressif32\libraries\ArduinoOTA)
|   |   |-- Networking @ 3.2.0 (License: Unknown, Path: C:\.platformio\packages\framework-arduinoespressif32\libraries\Network)
|   |   |-- Update @ 3.2.0 (License: Unknown, Path: C:\.platformio\packages\framework-arduinoespressif32\libraries\Update)
|   |   |-- ESPmDNS @ 3.2.0 (License: Unknown, Path: C:\.platformio\packages\framework-arduinoespressif32\libraries\ESPmDNS)
|   |-- Async TCP @ 3.1.4 (License: LGPL-3.0, Path: E:\My Drive\OpenHaldex\Can2Cluster\.pio\libdeps\esp32doit-devkit-v1\Async TCP)
|   |-- ESP Async WebServer @ 3.0.6 (License: LGPL-3.0, Path: E:\My Drive\OpenHaldex\Can2Cluster\.pio\libdeps\esp32doit-devkit-v1\ESP Async WebServer)
|   |   |-- Async TCP @ 3.1.4 (License: LGPL-3.0, Path: E:\My Drive\OpenHaldex\Can2Cluster\.pio\libdeps\esp32doit-devkit-v1\Async TCP)
|   |   |-- FS @ 3.2.0 (License: Unknown, Path: C:\.platformio\packages\framework-arduinoespressif32\libraries\FS)
|   |   |-- WebServer @ 3.2.0 (License: Unknown, Path: C:\.platformio\packages\framework-arduinoespressif32\libraries\WebServer)
|   |   |   |-- Networking @ 3.2.0 (License: Unknown, Path: C:\.platformio\packages\framework-arduinoespressif32\libraries\Network)
|   |   |   |-- FS @ 3.2.0 (License: Unknown, Path: C:\.platformio\packages\framework-arduinoespressif32\libraries\FS)
|   |   |-- WiFi @ 3.2.0 (License: Unknown, Path: C:\.platformio\packages\framework-arduinoespressif32\libraries\WiFi)
|   |   |   |-- Networking @ 3.2.0 (License: Unknown, Path: C:\.platformio\packages\framework-arduinoespressif32\libraries\Network)
|   |-- LittleFS @ 3.2.0 (License: Unknown, Path: C:\.platformio\packages\framework-arduinoespressif32\libraries\LittleFS)
|   |   |-- FS @ 3.2.0 (License: Unknown, Path: C:\.platformio\packages\framework-arduinoespressif32\libraries\FS)
|-- InterruptButton @ 2.0.2+sha.d68cf26 (License: Unknown, URI: git+https://github.com/rwmingis/InterruptButton, Path: E:\My Drive\OpenHaldex\Can2Cluster\.pio\libdeps\esp32doit-devkit-v1\InterruptButton)
|-- ESP32_CAN @ 0.3.1+sha.6d835ae (License: Unknown, URI: git+https://github.com/collin80/esp32_can, Path: E:\My Drive\OpenHaldex\Can2Cluster\.pio\libdeps\esp32doit-devkit-v1\ESP32_CAN)
|   |-- can_common @ 0.4.0+sha.8585f9d (License: Unknown, URI: git+https://github.com/collin80/can_common, Path: E:\My Drive\OpenHaldex\Can2Cluster\.pio\libdeps\esp32doit-devkit-v1\can_common)
|-- can_common @ 0.4.0+sha.8585f9d (License: Unknown, URI: git+https://github.com/collin80/can_common, Path: E:\My Drive\OpenHaldex\Can2Cluster\.pio\libdeps\esp32doit-devkit-v1\can_common)
|-- AsyncTCP @ 3.3.2 (License: LGPL-3.0, Path: E:\My Drive\OpenHaldex\Can2Cluster\.pio\libdeps\esp32doit-devkit-v1\AsyncTCP@3.3.2)
|   |-- Networking @ 3.2.0 (License: Unknown, Path: C:\.platformio\packages\framework-arduinoespressif32\libraries\Network)
|-- ESP Async WebServer @ 3.0.6 (License: LGPL-3.0, Path: E:\My Drive\OpenHaldex\Can2Cluster\.pio\libdeps\esp32doit-devkit-v1\ESP Async WebServer)
|   |-- Async TCP @ 3.1.4 (License: LGPL-3.0, Path: E:\My Drive\OpenHaldex\Can2Cluster\.pio\libdeps\esp32doit-devkit-v1\Async TCP)
|   |-- FS @ 3.2.0 (License: Unknown, Path: C:\.platformio\packages\framework-arduinoespressif32\libraries\FS)
|   |-- WebServer @ 3.2.0 (License: Unknown, Path: C:\.platformio\packages\framework-arduinoespressif32\libraries\WebServer)
|   |   |-- Networking @ 3.2.0 (License: Unknown, Path: C:\.platformio\packages\framework-arduinoespressif32\libraries\Network)
|   |   |-- FS @ 3.2.0 (License: Unknown, Path: C:\.platformio\packages\framework-arduinoespressif32\libraries\FS)
|   |-- WiFi @ 3.2.0 (License: Unknown, Path: C:\.platformio\packages\framework-arduinoespressif32\libraries\WiFi)
|   |   |-- Networking @ 3.2.0 (License: Unknown, Path: C:\.platformio\packages\framework-arduinoespressif32\libraries\Network)
|-- ArduinoJson @ 7.4.3 (License: Unknown, Path: E:\My Drive\OpenHaldex\Can2Cluster\.pio\libdeps\esp32doit-devkit-v1\ArduinoJson)
|-- ESPmDNS @ 3.2.0 (License: Unknown, Path: C:\.platformio\packages\framework-arduinoespressif32\libraries\ESPmDNS)
|-- Preferences @ 3.2.0 (License: Unknown, Path: C:\.platformio\packages\framework-arduinoespressif32\libraries\Preferences)
|-- WiFi @ 3.2.0 (License: Unknown, Path: C:\.platformio\packages\framework-arduinoespressif32\libraries\WiFi)
|   |-- Networking @ 3.2.0 (License: Unknown, Path: C:\.platformio\packages\framework-arduinoespressif32\libraries\Network)
Building in release mode
Using tempfile E:\My Drive\OpenHaldex\Can2Cluster\.pio\build\esp32doit-devkit-v1\tmpx4au7mxg.tmp for command line:
xtensa-esp32-elf-g++ -o .pio/build/esp32doit-devkit-v1/src/can2cluster_io.cpp.o -c -Wno-frame-address -fno-builtin-memcpy -fno-builtin-memset -fno-builtin-bzero -fno-builtin-stpcpy -fno-builtin-strncpy -std=gnu++2b -fexceptions -fno-rtti -fuse-cxa-atexit -std=gnu++2a -Werror=return-type -Os -mlongcalls -ffunction-sections -fdata-sections -Wno-error=unused-function -Wno-error=unused-variable -Wno-error=unused-but-set-variable -Wno-error=deprecated-declarations -Wno-error=extra -Wno-unused-parameter -Wno-sign-compare -Wno-enum-conversion -gdwarf-4 -ggdb -mdisable-hardware-atomics -freorder-blocks -Wwrite-strings -fstack-protector -fstrict-volatile-bitfields -fno-jump-tables -fno-tree-switch-conversion "-DCHIP_ADDRESS_RESOLVE_IMPL_INCLUDE_HEADER=<lib/address_resolve/AddressResolve_DefaultImpl.h>" -MMD -iprefix C:/.platformio/packages/framework-arduinoespressif32-libs/esp32/include -iwithprefix/newlib/platform_include -iwithprefix/freertos/config/include -iwithprefix/freertos/config/include/freertos -iwithprefix/freertos/config/xtensa/include -iwithprefix/freertos/FreeRTOS-Kernel/include -iwithprefix/freertos/FreeRTOS-Kernel/portable/xtensa/include -iwithprefix/freertos/FreeRTOS-Kernel/portable/xtensa/include/freertos -iwithprefix/freertos/esp_additions/include -iwithprefix/esp_hw_support/include -iwithprefix/esp_hw_support/include/soc -iwithprefix/esp_hw_support/include/soc/esp32 -iwithprefix/esp_hw_support/dma/include -iwithprefix/esp_hw_support/ldo/include -iwithprefix/esp_hw_support/debug_probe/include -iwithprefix/esp_hw_support/port/esp32 -iwithprefix/esp_hw_support/port/esp32/include -iwithprefix/heap/include -iwithprefix/heap/tlsf -iwithprefix/log/include -iwithprefix/soc/include -iwithprefix/soc/esp32 -iwithprefix/soc/esp32/include -iwithprefix/soc/esp32/register -iwithprefix/hal/platform_port/include -iwithprefix/hal/esp32/include -iwithprefix/hal/include -iwithprefix/esp_rom/include -iwithprefix/esp_rom/esp32/include -iwithprefix/esp_rom/esp32/include/esp32 -iwithprefix/esp_rom/esp32 -iwithprefix/esp_common/include -iwithprefix/esp_system/include -iwithprefix/esp_system/port/soc -iwithprefix/esp_system/port/include/private -iwithprefix/xtensa/esp32/include -iwithprefix/xtensa/include -iwithprefix/xtensa/deprecated_include -iwithprefix/esp_timer/include -iwithprefix/lwip/include -iwithprefix/lwip/include/apps -iwithprefix/lwip/include/apps/sntp -iwithprefix/lwip/lwip/src/include -iwithprefix/lwip/port/include -iwithprefix/lwip/port/freertos/include -iwithprefix/lwip/port/esp32xx/include -iwithprefix/lwip/port/esp32xx/include/arch -iwithprefix/lwip/port/esp32xx/include/sys -iwithprefix/espressif__esp-tflite-micro -iwithprefix/espressif__esp-tflite-micro/third_party/gemmlowp -iwithprefix/espressif__esp-tflite-micro/third_party/flatbuffers/include -iwithprefix/espressif__esp-tflite-micro/third_party/ruy -iwithprefix/espressif__esp-tflite-micro/third_party/kissfft -iwithprefix/espressif__esp32-camera/driver/include -iwithprefix/espressif__esp32-camera/conversions/include -iwithprefix/driver/deprecated -iwithprefix/driver/i2c/include -iwithprefix/driver/touch_sensor/include -iwithprefix/driver/twai/include -iwithprefix/driver/touch_sensor/esp32/include -iwithprefix/esp_pm/include -iwithprefix/esp_ringbuf/include -iwithprefix/esp_driver_gpio/include -iwithprefix/esp_driver_pcnt/include -iwithprefix/esp_driver_gptimer/include -iwithprefix/esp_driver_spi/include -iwithprefix/esp_driver_mcpwm/include -iwithprefix/esp_driver_ana_cmpr/include -iwithprefix/esp_driver_i2s/include -iwithprefix/esp_driver_sdmmc/include -iwithprefix/sdmmc/include -iwithprefix/esp_driver_sdspi/include -iwithprefix/esp_driver_sdio/include -iwithprefix/esp_driver_dac/include -iwithprefix/esp_driver_rmt/include -iwithprefix/esp_driver_tsens/include -iwithprefix/esp_driver_sdm/include -iwithprefix/esp_driver_i2c/include -iwithprefix/esp_driver_uart/include -iwithprefix/vfs/include -iwithprefix/esp_driver_ledc/include -iwithprefix/esp_driver_parlio/include -iwithprefix/esp_driver_usb_serial_jtag/include -iwithprefix/espressif__esp_matter/connectedhomeip/connectedhomeip/src -iwithprefix/espressif__esp_matter/connectedhomeip/connectedhomeip/src/app/ember_coupling -iwithprefix/espressif__esp_matter/connectedhomeip/connectedhomeip/src/include -iwithprefix/espressif__esp_matter/connectedhomeip/connectedhomeip/src/lib -iwithprefix/espressif__esp_matter/connectedhomeip/connectedhomeip/src/lib/dnssd -iwithprefix/espressif__esp_matter/connectedhomeip/connectedhomeip/src/platform/OpenThread -iwithprefix/espressif__esp_matter/connectedhomeip/connectedhomeip/third_party/jsoncpp/repo/include -iwithprefix/espressif__esp_matter/connectedhomeip/connectedhomeip/third_party/nlfaultinjection/include -iwithprefix/espressif__esp_matter/connectedhomeip/connectedhomeip/third_party/nlassert/repo/include -iwithprefix/espressif__esp_matter/connectedhomeip/connectedhomeip/third_party/nlio/repo/include -iwithprefix/espressif__esp_matter/connectedhomeip/connectedhomeip/zzz_generated/app-common -iwithprefix/esp-idf/espressif__esp_matter -iwithprefix/esp_matter/zap_common -iwithprefix/esp_matter -iwithprefix/esp_matter/utils -iwithprefix/esp_matter_bridge -iwithprefix/esp_matter_console -iwithprefix/espressif__esp_matter/connectedhomeip/connectedhomeip/src/platform/ESP32 -iwithprefix/espressif__esp_matter/connectedhomeip/connectedhomeip/src/platform/ESP32/bluedroid -iwithprefix/espressif__esp_matter/connectedhomeip/connectedhomeip/src/platform/ESP32/nimble -iwithprefix/espressif__esp_matter/connectedhomeip/connectedhomeip/src/platform/ESP32/route_hook -iwithprefix/esp_eth/include -iwithprefix/esp_event/include -iwithprefix/bt/include/esp32/include -iwithprefix/bt/common/osi/include -iwithprefix/bt/common/api/include/api -iwithprefix/bt/common/btc/profile/esp/blufi/include -iwithprefix/bt/common/btc/profile/esp/include -iwithprefix/bt/common/hci_log/include -iwithprefix/bt/common/ble_log/include -iwithprefix/bt/host/bluedroid/api/include/api -iwithprefix/bt/esp_ble_mesh/common/include -iwithprefix/bt/esp_ble_mesh/common/tinycrypt/include -iwithprefix/bt/esp_ble_mesh/core -iwithprefix/bt/esp_ble_mesh/core/include -iwithprefix/bt/esp_ble_mesh/core/storage -iwithprefix/bt/esp_ble_mesh/btc/include -iwithprefix/bt/esp_ble_mesh/models/common/include -iwithprefix/bt/esp_ble_mesh/models/client/include -iwithprefix/bt/esp_ble_mesh/models/server/include -iwithprefix/bt/esp_ble_mesh/api/core/include -iwithprefix/bt/esp_ble_mesh/api/models/include -iwithprefix/bt/esp_ble_mesh/api -iwithprefix/bt/esp_ble_mesh/lib/include -iwithprefix/bt/esp_ble_mesh/v1.1/api/core/include -iwithprefix/bt/esp_ble_mesh/v1.1/api/models/include -iwithprefix/bt/esp_ble_mesh/v1.1/btc/include -iwithprefix/bt/porting/ext/tinycrypt/include -iwithprefix/esp_wifi/include -iwithprefix/esp_wifi/include/local -iwithprefix/esp_wifi/wifi_apps/include -iwithprefix/esp_wifi/wifi_apps/nan_app/include -iwithprefix/esp_phy/include -iwithprefix/esp_phy/esp32/include -iwithprefix/esp_netif/include -iwithprefix/mbedtls/port/include -iwithprefix/mbedtls/mbedtls/include -iwithprefix/mbedtls/mbedtls/library -iwithprefix/mbedtls/esp_crt_bundle/include -iwithprefix/mbedtls/mbedtls/3rdparty/everest/include -iwithprefix/mbedtls/mbedtls/3rdparty/p256-m -iwithprefix/mbedtls/mbedtls/3rdparty/p256-m/p256-m -iwithprefix/fatfs/diskio -iwithprefix/fatfs/src -iwithprefix/fatfs/vfs -iwithprefix/wear_levelling/include -iwithprefix/esp_partition/include -iwithprefix/app_update/include -iwithprefix/bootloader_support/include -iwithprefix/bootloader_support/bootloader_flash/include -iwithprefix/esp_app_format/include -iwithprefix/esp_bootloader_format/include -iwithprefix/console -iwithprefix/esp_vfs_console/include -iwithprefix/openthread/include -iwithprefix/openthread/openthread/include -iwithprefix/nvs_flash/include -iwithprefix/spi_flash/include -iwithprefix/espressif__esp_secure_cert_mgr/include -iwithprefix/efuse/include -iwithprefix/efuse/esp32/include -iwithprefix/espressif__json_parser/include -iwithprefix/espressif__jsmn/include -iwithprefix/spiffs/include -iwithprefix/esp_http_client/include -iwithprefix/espressif__json_generator/include -iwithprefix/json/cJSON -iwithprefix/espressif__mdns/include -iwithprefix/espressif__esp_delta_ota/include -iwithprefix/espressif__esp_encrypted_img/include -iwithprefix/espressif__esp_insights/include -iwithprefix/espressif__esp_diagnostics/include -iwithprefix/esp_mm/include -iwithprefix/esp_security/include -iwithprefix/pthread/include -iwithprefix/app_trace/include -iwithprefix/wpa_supplicant/include -iwithprefix/wpa_supplicant/port/include -iwithprefix/wpa_supplicant/esp_supplicant/include -iwithprefix/esp_coex/include -iwithprefix/unity/include -iwithprefix/unity/unity/src -iwithprefix/cmock/CMock/src -iwithprefix/http_parser -iwithprefix/esp-tls -iwithprefix/esp-tls/esp-tls-crypto -iwithprefix/esp_adc/include -iwithprefix/esp_adc/interface -iwithprefix/esp_adc/esp32/include -iwithprefix/esp_adc/deprecated/include -iwithprefix/esp_driver_isp/include -iwithprefix/esp_driver_cam/include -iwithprefix/esp_driver_cam/interface -iwithprefix/esp_driver_jpeg/include -iwithprefix/esp_driver_ppa/include -iwithprefix/esp_gdbstub/include -iwithprefix/esp_hid/include -iwithprefix/tcp_transport/include -iwithprefix/esp_http_server/include -iwithprefix/esp_https_ota/include -iwithprefix/esp_https_server/include -iwithprefix/esp_psram/include -iwithprefix/esp_lcd/include -iwithprefix/esp_lcd/interface -iwithprefix/protobuf-c/protobuf-c -iwithprefix/protocomm/include/common -iwithprefix/protocomm/include/security -iwithprefix/protocomm/include/transports -iwithprefix/protocomm/include/crypto/srp6a -iwithprefix/protocomm/proto-c -iwithprefix/esp_local_ctrl/include -iwithprefix/espcoredump/include -iwithprefix/espcoredump/include/port/xtensa -iwithprefix/idf_test/include -iwithprefix/idf_test/include/esp32 -iwithprefix/ieee802154/include -iwithprefix/mqtt/esp-mqtt/include -iwithprefix/nvs_sec_provider/include -iwithprefix/perfmon/include -iwithprefix/rt/include -iwithprefix/ulp/ulp_common/include -iwithprefix/ulp/ulp_fsm/include -iwithprefix/ulp/ulp_fsm/include/esp32 -iwithprefix/wifi_provisioning/include -iwithprefix/espressif__esp-nn/include -iwithprefix/espressif__esp-nn/src/common -iwithprefix/espressif__rmaker_common/include -iwithprefix/espressif__cbor/port/include -iwithprefix/espressif__esp_diag_data_store/src/rtc_store -iwithprefix/espressif__esp_diag_data_store/include -iwithprefix/espressif__esp-serial-flasher/include -iwithprefix/espressif__esp-serial-flasher/port -iwithprefix/espressif__esp_rcp_update/include -iwithprefix/chmorgan__esp-libhelix-mp3/libhelix-mp3/pub -iwithprefix/espressif__esp-modbus/freemodbus/common/include -iwithprefix/espressif__esp-zboss-lib/include -iwithprefix/espressif__esp-zigbee-lib/include -iwithprefix/espressif__esp-zigbee-lib/include/radio_spinel -iwithprefix/espressif__libsodium/libsodium/src/libsodium/include -iwithprefix/espressif__libsodium/port_include -iwithprefix/espressif__esp-dsp/modules/dotprod/include -iwithprefix/espressif__esp-dsp/modules/support/include -iwithprefix/espressif__esp-dsp/modules/support/mem/include -iwithprefix/espressif__esp-dsp/modules/windows/include -iwithprefix/espressif__esp-dsp/modules/windows/hann/include -iwithprefix/espressif__esp-dsp/modules/windows/blackman/include -iwithprefix/espressif__esp-dsp/modules/windows/blackman_harris/include -iwithprefix/espressif__esp-dsp/modules/windows/blackman_nuttall/include -iwithprefix/espressif__esp-dsp/modules/windows/nuttall/include -iwithprefix/espressif__esp-dsp/modules/windows/flat_top/include -iwithprefix/espressif__esp-dsp/modules/iir/include -iwithprefix/espressif__esp-dsp/modules/fir/include -iwithprefix/espressif__esp-dsp/modules/math/include -iwithprefix/espressif__esp-dsp/modules/math/add/include -iwithprefix/espressif__esp-dsp/modules/math/sub/include -iwithprefix/espressif__esp-dsp/modules/math/mul/include -iwithprefix/espressif__esp-dsp/modules/math/addc/include -iwithprefix/espressif__esp-dsp/modules/math/mulc/include -iwithprefix/espressif__esp-dsp/modules/math/sqrt/include -iwithprefix/espressif__esp-dsp/modules/matrix/mul/include -iwithprefix/espressif__esp-dsp/modules/matrix/add/include -iwithprefix/espressif__esp-dsp/modules/matrix/addc/include -iwithprefix/espressif__esp-dsp/modules/matrix/mulc/include -iwithprefix/espressif__esp-dsp/modules/matrix/sub/include -iwithprefix/espressif__esp-dsp/modules/matrix/include -iwithprefix/espressif__esp-dsp/modules/fft/include -iwithprefix/espressif__esp-dsp/modules/dct/include -iwithprefix/espressif__esp-dsp/modules/conv/include -iwithprefix/espressif__esp-dsp/modules/common/include -iwithprefix/espressif__esp-dsp/modules/matrix/mul/test/include -iwithprefix/espressif__esp-dsp/modules/kalman/ekf/include -iwithprefix/espressif__esp-dsp/modules/kalman/ekf_imu13states/include -iwithprefix/espressif__esp_modem/include -iwithprefix/espressif__esp_schedule/include -iwithprefix/espressif__network_provisioning/include -iwithprefix/espressif__esp_rainmaker/include -iwithprefix/espressif__qrcode/include -iwithprefix/joltwallet__littlefs/include -iwithprefix/fb_gfx/include -DPLATFORMIO=60118 -DARDUINO_ESP32_DEV -DESP32_ARDUINO_LIB_BUILDER -DESP_MDNS_VERSION_NUMBER=\"1.8.2\" -DESP_PLATFORM -DIDF_VER=\"v5.4.1-1-g2f7dcd862a-dirty\" -DMBEDTLS_CONFIG_FILE=\"mbedtls/esp_config.h\" -DMD5_ENABLED=1 -DOPENTHREAD_CONFIG_FILE=\"openthread-core-esp32x-spinel-config.h\" -DOPENTHREAD_PROJECT_LIB_CONFIG_FILE=\"openthread-core-esp32x-spinel-config.h\" -DSERIAL_FLASHER_BOOT_HOLD_TIME_MS=50 -DSERIAL_FLASHER_RESET_HOLD_TIME_MS=100 -DSOC_MMU_PAGE_SIZE=CONFIG_MMU_PAGE_SIZE -DSOC_XTAL_FREQ_MHZ=CONFIG_XTAL_FREQ -DUNITY_INCLUDE_CONFIG_H -D_GLIBCXX_HAVE_POSIX_SEMAPHORE -D_GLIBCXX_USE_POSIX_SEMAPHORE -D_GNU_SOURCE -D_POSIX_READER_WRITER_LOCKS -DTF_LITE_STATIC_MEMORY -DCHIP_CONFIG_SOFTWARE_VERSION_NUMBER=0 -DNDEBUG -DCHIP_MINMDNS_DEFAULT_POLICY=1 -DCHIP_MINMDNS_USE_EPHEMERAL_UNICAST_PORT=0 -DCHIP_MINMDNS_HIGH_VERBOSITY=0 -DCHIP_DNSSD_DEFAULT_MINIMAL=true -DCHIP_DNSSD_DEFAULT_NONE=false -DCHIP_DNSSD_DEFAULT_PLATFORM=false -DARDUINO_ARCH_ESP32 -DCHIP_HAVE_CONFIG_H -DESP32=ESP32 -DF_CPU=240000000L -DARDUINO=10812 -DARDUINO_VARIANT=\"doitESP32devkitV1\" "-DARDUINO_BOARD=\"DOIT ESP32 DEVKIT V1\"" -DARDUINO_PARTITION_default -Iinclude -Isrc -IC:/.platformio/packages/framework-arduinoespressif32/libraries/Preferences/src -I.pio/libdeps/esp32doit-devkit-v1/AsyncTCP@3.3.2/src -I.pio/libdeps/esp32doit-devkit-v1/ESP32_CAN/src -I.pio/libdeps/esp32doit-devkit-v1/can_common/src -I.pio/libdeps/esp32doit-devkit-v1/InterruptButton -I.pio/libdeps/esp32doit-devkit-v1/ESPUI/src -IC:/.platformio/packages/framework-arduinoespressif32/libraries/LittleFS/src "-I.pio/libdeps/esp32doit-devkit-v1/ESP Async WebServer/src" -IC:/.platformio/packages/framework-arduinoespressif32/libraries/WebServer/src -IC:/.platformio/packages/framework-arduinoespressif32/libraries/ArduinoOTA/src -IC:/.platformio/packages/framework-arduinoespressif32/libraries/ESPmDNS/src -IC:/.platformio/packages/framework-arduinoespressif32/libraries/Update/src -I.pio/libdeps/esp32doit-devkit-v1/ESPAsyncWebServer/src -IC:/.platformio/packages/framework-arduinoespressif32/libraries/FS/src -I.pio/libdeps/esp32doit-devkit-v1/ArduinoJson/src "-I.pio/libdeps/esp32doit-devkit-v1/Async TCP/src" -IC:/.platformio/packages/framework-arduinoespressif32/libraries/WiFi/src -IC:/.platformio/packages/framework-arduinoespressif32/libraries/Network/src -I.pio/libdeps/esp32doit-devkit-v1/TinyGPSPlus/src -I.pio/libdeps/esp32doit-devkit-v1/EspSoftwareSerial/src -I.pio/libdeps/esp32doit-devkit-v1/ghostl/src -IC:/.platformio/packages/framework-arduinoespressif32-libs/esp32/dio_qspi/include -IC:/.platformio/packages/framework-arduinoespressif32/cores/esp32 -IC:/.platformio/packages/framework-arduinoespressif32/variants/doitESP32devkitV1 src/can2cluster_io.cpp
xtensa-esp32-elf-g++ "@E:\My Drive\OpenHaldex\Can2Cluster\.pio\build\esp32doit-devkit-v1\tmpx4au7mxg.tmp"
Using tempfile E:\My Drive\OpenHaldex\Can2Cluster\.pio\build\esp32doit-devkit-v1\tmpeau4qz7c.tmp for command line:
xtensa-esp32-elf-g++ -o .pio/build/esp32doit-devkit-v1/libf48/ESPAsyncWebServer/AsyncEventSource.cpp.o -c -Wno-frame-address -fno-builtin-memcpy -fno-builtin-memset -fno-builtin-bzero -fno-builtin-stpcpy -fno-builtin-strncpy -std=gnu++2b -fexceptions -fno-rtti -fuse-cxa-atexit -std=gnu++2a -Werror=return-type -Os -mlongcalls -ffunction-sections -fdata-sections -Wno-error=unused-function -Wno-error=unused-variable -Wno-error=unused-but-set-variable -Wno-error=deprecated-declarations -Wno-error=extra -Wno-unused-parameter -Wno-sign-compare -Wno-enum-conversion -gdwarf-4 -ggdb -mdisable-hardware-atomics -freorder-blocks -Wwrite-strings -fstack-protector -fstrict-volatile-bitfields -fno-jump-tables -fno-tree-switch-conversion "-DCHIP_ADDRESS_RESOLVE_IMPL_INCLUDE_HEADER=<lib/address_resolve/AddressResolve_DefaultImpl.h>" -MMD -iprefix C:/.platformio/packages/framework-arduinoespressif32-libs/esp32/include -iwithprefix/newlib/platform_include -iwithprefix/freertos/config/include -iwithprefix/freertos/config/include/freertos -iwithprefix/freertos/config/xtensa/include -iwithprefix/freertos/FreeRTOS-Kernel/include -iwithprefix/freertos/FreeRTOS-Kernel/portable/xtensa/include -iwithprefix/freertos/FreeRTOS-Kernel/portable/xtensa/include/freertos -iwithprefix/freertos/esp_additions/include -iwithprefix/esp_hw_support/include -iwithprefix/esp_hw_support/include/soc -iwithprefix/esp_hw_support/include/soc/esp32 -iwithprefix/esp_hw_support/dma/include -iwithprefix/esp_hw_support/ldo/include -iwithprefix/esp_hw_support/debug_probe/include -iwithprefix/esp_hw_support/port/esp32 -iwithprefix/esp_hw_support/port/esp32/include -iwithprefix/heap/include -iwithprefix/heap/tlsf -iwithprefix/log/include -iwithprefix/soc/include -iwithprefix/soc/esp32 -iwithprefix/soc/esp32/include -iwithprefix/soc/esp32/register -iwithprefix/hal/platform_port/include -iwithprefix/hal/esp32/include -iwithprefix/hal/include -iwithprefix/esp_rom/include -iwithprefix/esp_rom/esp32/include -iwithprefix/esp_rom/esp32/include/esp32 -iwithprefix/esp_rom/esp32 -iwithprefix/esp_common/include -iwithprefix/esp_system/include -iwithprefix/esp_system/port/soc -iwithprefix/esp_system/port/include/private -iwithprefix/xtensa/esp32/include -iwithprefix/xtensa/include -iwithprefix/xtensa/deprecated_include -iwithprefix/esp_timer/include -iwithprefix/lwip/include -iwithprefix/lwip/include/apps -iwithprefix/lwip/include/apps/sntp -iwithprefix/lwip/lwip/src/include -iwithprefix/lwip/port/include -iwithprefix/lwip/port/freertos/include -iwithprefix/lwip/port/esp32xx/include -iwithprefix/lwip/port/esp32xx/include/arch -iwithprefix/lwip/port/esp32xx/include/sys -iwithprefix/espressif__esp-tflite-micro -iwithprefix/espressif__esp-tflite-micro/third_party/gemmlowp -iwithprefix/espressif__esp-tflite-micro/third_party/flatbuffers/include -iwithprefix/espressif__esp-tflite-micro/third_party/ruy -iwithprefix/espressif__esp-tflite-micro/third_party/kissfft -iwithprefix/espressif__esp32-camera/driver/include -iwithprefix/espressif__esp32-camera/conversions/include -iwithprefix/driver/deprecated -iwithprefix/driver/i2c/include -iwithprefix/driver/touch_sensor/include -iwithprefix/driver/twai/include -iwithprefix/driver/touch_sensor/esp32/include -iwithprefix/esp_pm/include -iwithprefix/esp_ringbuf/include -iwithprefix/esp_driver_gpio/include -iwithprefix/esp_driver_pcnt/include -iwithprefix/esp_driver_gptimer/include -iwithprefix/esp_driver_spi/include -iwithprefix/esp_driver_mcpwm/include -iwithprefix/esp_driver_ana_cmpr/include -iwithprefix/esp_driver_i2s/include -iwithprefix/esp_driver_sdmmc/include -iwithprefix/sdmmc/include -iwithprefix/esp_driver_sdspi/include -iwithprefix/esp_driver_sdio/include -iwithprefix/esp_driver_dac/include -iwithprefix/esp_driver_rmt/include -iwithprefix/esp_driver_tsens/include -iwithprefix/esp_driver_sdm/include -iwithprefix/esp_driver_i2c/include -iwithprefix/esp_driver_uart/include -iwithprefix/vfs/include -iwithprefix/esp_driver_ledc/include -iwithprefix/esp_driver_parlio/include -iwithprefix/esp_driver_usb_serial_jtag/include -iwithprefix/espressif__esp_matter/connectedhomeip/connectedhomeip/src -iwithprefix/espressif__esp_matter/connectedhomeip/connectedhomeip/src/app/ember_coupling -iwithprefix/espressif__esp_matter/connectedhomeip/connectedhomeip/src/include -iwithprefix/espressif__esp_matter/connectedhomeip/connectedhomeip/src/lib -iwithprefix/espressif__esp_matter/connectedhomeip/connectedhomeip/src/lib/dnssd -iwithprefix/espressif__esp_matter/connectedhomeip/connectedhomeip/src/platform/OpenThread -iwithprefix/espressif__esp_matter/connectedhomeip/connectedhomeip/third_party/jsoncpp/repo/include -iwithprefix/espressif__esp_matter/connectedhomeip/connectedhomeip/third_party/nlfaultinjection/include -iwithprefix/espressif__esp_matter/connectedhomeip/connectedhomeip/third_party/nlassert/repo/include -iwithprefix/espressif__esp_matter/connectedhomeip/connectedhomeip/third_party/nlio/repo/include -iwithprefix/espressif__esp_matter/connectedhomeip/connectedhomeip/zzz_generated/app-common -iwithprefix/esp-idf/espressif__esp_matter -iwithprefix/esp_matter/zap_common -iwithprefix/esp_matter -iwithprefix/esp_matter/utils -iwithprefix/esp_matter_bridge -iwithprefix/esp_matter_console -iwithprefix/espressif__esp_matter/connectedhomeip/connectedhomeip/src/platform/ESP32 -iwithprefix/espressif__esp_matter/connectedhomeip/connectedhomeip/src/platform/ESP32/bluedroid -iwithprefix/espressif__esp_matter/connectedhomeip/connectedhomeip/src/platform/ESP32/nimble -iwithprefix/espressif__esp_matter/connectedhomeip/connectedhomeip/src/platform/ESP32/route_hook -iwithprefix/esp_eth/include -iwithprefix/esp_event/include -iwithprefix/bt/include/esp32/include -iwithprefix/bt/common/osi/include -iwithprefix/bt/common/api/include/api -iwithprefix/bt/common/btc/profile/esp/blufi/include -iwithprefix/bt/common/btc/profile/esp/include -iwithprefix/bt/common/hci_log/include -iwithprefix/bt/common/ble_log/include -iwithprefix/bt/host/bluedroid/api/include/api -iwithprefix/bt/esp_ble_mesh/common/include -iwithprefix/bt/esp_ble_mesh/common/tinycrypt/include -iwithprefix/bt/esp_ble_mesh/core -iwithprefix/bt/esp_ble_mesh/core/include -iwithprefix/bt/esp_ble_mesh/core/storage -iwithprefix/bt/esp_ble_mesh/btc/include -iwithprefix/bt/esp_ble_mesh/models/common/include -iwithprefix/bt/esp_ble_mesh/models/client/include -iwithprefix/bt/esp_ble_mesh/models/server/include -iwithprefix/bt/esp_ble_mesh/api/core/include -iwithprefix/bt/esp_ble_mesh/api/models/include -iwithprefix/bt/esp_ble_mesh/api -iwithprefix/bt/esp_ble_mesh/lib/include -iwithprefix/bt/esp_ble_mesh/v1.1/api/core/include -iwithprefix/bt/esp_ble_mesh/v1.1/api/models/include -iwithprefix/bt/esp_ble_mesh/v1.1/btc/include -iwithprefix/bt/porting/ext/tinycrypt/include -iwithprefix/esp_wifi/include -iwithprefix/esp_wifi/include/local -iwithprefix/esp_wifi/wifi_apps/include -iwithprefix/esp_wifi/wifi_apps/nan_app/include -iwithprefix/esp_phy/include -iwithprefix/esp_phy/esp32/include -iwithprefix/esp_netif/include -iwithprefix/mbedtls/port/include -iwithprefix/mbedtls/mbedtls/include -iwithprefix/mbedtls/mbedtls/library -iwithprefix/mbedtls/esp_crt_bundle/include -iwithprefix/mbedtls/mbedtls/3rdparty/everest/include -iwithprefix/mbedtls/mbedtls/3rdparty/p256-m -iwithprefix/mbedtls/mbedtls/3rdparty/p256-m/p256-m -iwithprefix/fatfs/diskio -iwithprefix/fatfs/src -iwithprefix/fatfs/vfs -iwithprefix/wear_levelling/include -iwithprefix/esp_partition/include -iwithprefix/app_update/include -iwithprefix/bootloader_support/include -iwithprefix/bootloader_support/bootloader_flash/include -iwithprefix/esp_app_format/include -iwithprefix/esp_bootloader_format/include -iwithprefix/console -iwithprefix/esp_vfs_console/include -iwithprefix/openthread/include -iwithprefix/openthread/openthread/include -iwithprefix/nvs_flash/include -iwithprefix/spi_flash/include -iwithprefix/espressif__esp_secure_cert_mgr/include -iwithprefix/efuse/include -iwithprefix/efuse/esp32/include -iwithprefix/espressif__json_parser/include -iwithprefix/espressif__jsmn/include -iwithprefix/spiffs/include -iwithprefix/esp_http_client/include -iwithprefix/espressif__json_generator/include -iwithprefix/json/cJSON -iwithprefix/espressif__mdns/include -iwithprefix/espressif__esp_delta_ota/include -iwithprefix/espressif__esp_encrypted_img/include -iwithprefix/espressif__esp_insights/include -iwithprefix/espressif__esp_diagnostics/include -iwithprefix/esp_mm/include -iwithprefix/esp_security/include -iwithprefix/pthread/include -iwithprefix/app_trace/include -iwithprefix/wpa_supplicant/include -iwithprefix/wpa_supplicant/port/include -iwithprefix/wpa_supplicant/esp_supplicant/include -iwithprefix/esp_coex/include -iwithprefix/unity/include -iwithprefix/unity/unity/src -iwithprefix/cmock/CMock/src -iwithprefix/http_parser -iwithprefix/esp-tls -iwithprefix/esp-tls/esp-tls-crypto -iwithprefix/esp_adc/include -iwithprefix/esp_adc/interface -iwithprefix/esp_adc/esp32/include -iwithprefix/esp_adc/deprecated/include -iwithprefix/esp_driver_isp/include -iwithprefix/esp_driver_cam/include -iwithprefix/esp_driver_cam/interface -iwithprefix/esp_driver_jpeg/include -iwithprefix/esp_driver_ppa/include -iwithprefix/esp_gdbstub/include -iwithprefix/esp_hid/include -iwithprefix/tcp_transport/include -iwithprefix/esp_http_server/include -iwithprefix/esp_https_ota/include -iwithprefix/esp_https_server/include -iwithprefix/esp_psram/include -iwithprefix/esp_lcd/include -iwithprefix/esp_lcd/interface -iwithprefix/protobuf-c/protobuf-c -iwithprefix/protocomm/include/common -iwithprefix/protocomm/include/security -iwithprefix/protocomm/include/transports -iwithprefix/protocomm/include/crypto/srp6a -iwithprefix/protocomm/proto-c -iwithprefix/esp_local_ctrl/include -iwithprefix/espcoredump/include -iwithprefix/espcoredump/include/port/xtensa -iwithprefix/idf_test/include -iwithprefix/idf_test/include/esp32 -iwithprefix/ieee802154/include -iwithprefix/mqtt/esp-mqtt/include -iwithprefix/nvs_sec_provider/include -iwithprefix/perfmon/include -iwithprefix/rt/include -iwithprefix/ulp/ulp_common/include -iwithprefix/ulp/ulp_fsm/include -iwithprefix/ulp/ulp_fsm/include/esp32 -iwithprefix/wifi_provisioning/include -iwithprefix/espressif__esp-nn/include -iwithprefix/espressif__esp-nn/src/common -iwithprefix/espressif__rmaker_common/include -iwithprefix/espressif__cbor/port/include -iwithprefix/espressif__esp_diag_data_store/src/rtc_store -iwithprefix/espressif__esp_diag_data_store/include -iwithprefix/espressif__esp-serial-flasher/include -iwithprefix/espressif__esp-serial-flasher/port -iwithprefix/espressif__esp_rcp_update/include -iwithprefix/chmorgan__esp-libhelix-mp3/libhelix-mp3/pub -iwithprefix/espressif__esp-modbus/freemodbus/common/include -iwithprefix/espressif__esp-zboss-lib/include -iwithprefix/espressif__esp-zigbee-lib/include -iwithprefix/espressif__esp-zigbee-lib/include/radio_spinel -iwithprefix/espressif__libsodium/libsodium/src/libsodium/include -iwithprefix/espressif__libsodium/port_include -iwithprefix/espressif__esp-dsp/modules/dotprod/include -iwithprefix/espressif__esp-dsp/modules/support/include -iwithprefix/espressif__esp-dsp/modules/support/mem/include -iwithprefix/espressif__esp-dsp/modules/windows/include -iwithprefix/espressif__esp-dsp/modules/windows/hann/include -iwithprefix/espressif__esp-dsp/modules/windows/blackman/include -iwithprefix/espressif__esp-dsp/modules/windows/blackman_harris/include -iwithprefix/espressif__esp-dsp/modules/windows/blackman_nuttall/include -iwithprefix/espressif__esp-dsp/modules/windows/nuttall/include -iwithprefix/espressif__esp-dsp/modules/windows/flat_top/include -iwithprefix/espressif__esp-dsp/modules/iir/include -iwithprefix/espressif__esp-dsp/modules/fir/include -iwithprefix/espressif__esp-dsp/modules/math/include -iwithprefix/espressif__esp-dsp/modules/math/add/include -iwithprefix/espressif__esp-dsp/modules/math/sub/include -iwithprefix/espressif__esp-dsp/modules/math/mul/include -iwithprefix/espressif__esp-dsp/modules/math/addc/include -iwithprefix/espressif__esp-dsp/modules/math/mulc/include -iwithprefix/espressif__esp-dsp/modules/math/sqrt/include -iwithprefix/espressif__esp-dsp/modules/matrix/mul/include -iwithprefix/espressif__esp-dsp/modules/matrix/add/include -iwithprefix/espressif__esp-dsp/modules/matrix/addc/include -iwithprefix/espressif__esp-dsp/modules/matrix/mulc/include -iwithprefix/espressif__esp-dsp/modules/matrix/sub/include -iwithprefix/espressif__esp-dsp/modules/matrix/include -iwithprefix/espressif__esp-dsp/modules/fft/include -iwithprefix/espressif__esp-dsp/modules/dct/include -iwithprefix/espressif__esp-dsp/modules/conv/include -iwithprefix/espressif__esp-dsp/modules/common/include -iwithprefix/espressif__esp-dsp/modules/matrix/mul/test/include -iwithprefix/espressif__esp-dsp/modules/kalman/ekf/include -iwithprefix/espressif__esp-dsp/modules/kalman/ekf_imu13states/include -iwithprefix/espressif__esp_modem/include -iwithprefix/espressif__esp_schedule/include -iwithprefix/espressif__network_provisioning/include -iwithprefix/espressif__esp_rainmaker/include -iwithprefix/espressif__qrcode/include -iwithprefix/joltwallet__littlefs/include -iwithprefix/fb_gfx/include -DPLATFORMIO=60118 -DARDUINO_ESP32_DEV -DESP32_ARDUINO_LIB_BUILDER -DESP_MDNS_VERSION_NUMBER=\"1.8.2\" -DESP_PLATFORM -DIDF_VER=\"v5.4.1-1-g2f7dcd862a-dirty\" -DMBEDTLS_CONFIG_FILE=\"mbedtls/esp_config.h\" -DMD5_ENABLED=1 -DOPENTHREAD_CONFIG_FILE=\"openthread-core-esp32x-spinel-config.h\" -DOPENTHREAD_PROJECT_LIB_CONFIG_FILE=\"openthread-core-esp32x-spinel-config.h\" -DSERIAL_FLASHER_BOOT_HOLD_TIME_MS=50 -DSERIAL_FLASHER_RESET_HOLD_TIME_MS=100 -DSOC_MMU_PAGE_SIZE=CONFIG_MMU_PAGE_SIZE -DSOC_XTAL_FREQ_MHZ=CONFIG_XTAL_FREQ -DUNITY_INCLUDE_CONFIG_H -D_GLIBCXX_HAVE_POSIX_SEMAPHORE -D_GLIBCXX_USE_POSIX_SEMAPHORE -D_GNU_SOURCE -D_POSIX_READER_WRITER_LOCKS -DTF_LITE_STATIC_MEMORY -DCHIP_CONFIG_SOFTWARE_VERSION_NUMBER=0 -DNDEBUG -DCHIP_MINMDNS_DEFAULT_POLICY=1 -DCHIP_MINMDNS_USE_EPHEMERAL_UNICAST_PORT=0 -DCHIP_MINMDNS_HIGH_VERBOSITY=0 -DCHIP_DNSSD_DEFAULT_MINIMAL=true -DCHIP_DNSSD_DEFAULT_NONE=false -DCHIP_DNSSD_DEFAULT_PLATFORM=false -DARDUINO_ARCH_ESP32 -DCHIP_HAVE_CONFIG_H -DESP32=ESP32 -DF_CPU=240000000L -DARDUINO=10812 -DARDUINO_VARIANT=\"doitESP32devkitV1\" "-DARDUINO_BOARD=\"DOIT ESP32 DEVKIT V1\"" -DARDUINO_PARTITION_default -I.pio/libdeps/esp32doit-devkit-v1/ESPAsyncWebServer/src -IC:/.platformio/packages/framework-arduinoespressif32/libraries/FS/src -I.pio/libdeps/esp32doit-devkit-v1/ArduinoJson/src "-I.pio/libdeps/esp32doit-devkit-v1/Async TCP/src" -IC:/.platformio/packages/framework-arduinoespressif32/libraries/WiFi/src -IC:/.platformio/packages/framework-arduinoespressif32/libraries/Network/src -IC:/.platformio/packages/framework-arduinoespressif32-libs/esp32/dio_qspi/include -IC:/.platformio/packages/framework-arduinoespressif32/cores/esp32 -IC:/.platformio/packages/framework-arduinoespressif32/variants/doitESP32devkitV1 .pio/libdeps/esp32doit-devkit-v1/ESPAsyncWebServer/src/AsyncEventSource.cpp
xtensa-esp32-elf-g++ "@E:\My Drive\OpenHaldex\Can2Cluster\.pio\build\esp32doit-devkit-v1\tmpeau4qz7c.tmp"
Using tempfile E:\My Drive\OpenHaldex\Can2Cluster\.pio\build\esp32doit-devkit-v1\tmp7o1hnwga.tmp for command line:
xtensa-esp32-elf-g++ -o .pio/build/esp32doit-devkit-v1/libf48/ESPAsyncWebServer/AsyncJson.cpp.o -c -Wno-frame-address -fno-builtin-memcpy -fno-builtin-memset -fno-builtin-bzero -fno-builtin-stpcpy -fno-builtin-strncpy -std=gnu++2b -fexceptions -fno-rtti -fuse-cxa-atexit -std=gnu++2a -Werror=return-type -Os -mlongcalls -ffunction-sections -fdata-sections -Wno-error=unused-function -Wno-error=unused-variable -Wno-error=unused-but-set-variable -Wno-error=deprecated-declarations -Wno-error=extra -Wno-unused-parameter -Wno-sign-compare -Wno-enum-conversion -gdwarf-4 -ggdb -mdisable-hardware-atomics -freorder-blocks -Wwrite-strings -fstack-protector -fstrict-volatile-bitfields -fno-jump-tables -fno-tree-switch-conversion "-DCHIP_ADDRESS_RESOLVE_IMPL_INCLUDE_HEADER=<lib/address_resolve/AddressResolve_DefaultImpl.h>" -MMD -iprefix C:/.platformio/packages/framework-arduinoespressif32-libs/esp32/include -iwithprefix/newlib/platform_include -iwithprefix/freertos/config/include -iwithprefix/freertos/config/include/freertos -iwithprefix/freertos/config/xtensa/include -iwithprefix/freertos/FreeRTOS-Kernel/include -iwithprefix/freertos/FreeRTOS-Kernel/portable/xtensa/include -iwithprefix/freertos/FreeRTOS-Kernel/portable/xtensa/include/freertos -iwithprefix/freertos/esp_additions/include -iwithprefix/esp_hw_support/include -iwithprefix/esp_hw_support/include/soc -iwithprefix/esp_hw_support/include/soc/esp32 -iwithprefix/esp_hw_support/dma/include -iwithprefix/esp_hw_support/ldo/include -iwithprefix/esp_hw_support/debug_probe/include -iwithprefix/esp_hw_support/port/esp32 -iwithprefix/esp_hw_support/port/esp32/include -iwithprefix/heap/include -iwithprefix/heap/tlsf -iwithprefix/log/include -iwithprefix/soc/include -iwithprefix/soc/esp32 -iwithprefix/soc/esp32/include -iwithprefix/soc/esp32/register -iwithprefix/hal/platform_port/include -iwithprefix/hal/esp32/include -iwithprefix/hal/include -iwithprefix/esp_rom/include -iwithprefix/esp_rom/esp32/include -iwithprefix/esp_rom/esp32/include/esp32 -iwithprefix/esp_rom/esp32 -iwithprefix/esp_common/include -iwithprefix/esp_system/include -iwithprefix/esp_system/port/soc -iwithprefix/esp_system/port/include/private -iwithprefix/xtensa/esp32/include -iwithprefix/xtensa/include -iwithprefix/xtensa/deprecated_include -iwithprefix/esp_timer/include -iwithprefix/lwip/include -iwithprefix/lwip/include/apps -iwithprefix/lwip/include/apps/sntp -iwithprefix/lwip/lwip/src/include -iwithprefix/lwip/port/include -iwithprefix/lwip/port/freertos/include -iwithprefix/lwip/port/esp32xx/include -iwithprefix/lwip/port/esp32xx/include/arch -iwithprefix/lwip/port/esp32xx/include/sys -iwithprefix/espressif__esp-tflite-micro -iwithprefix/espressif__esp-tflite-micro/third_party/gemmlowp -iwithprefix/espressif__esp-tflite-micro/third_party/flatbuffers/include -iwithprefix/espressif__esp-tflite-micro/third_party/ruy -iwithprefix/espressif__esp-tflite-micro/third_party/kissfft -iwithprefix/espressif__esp32-camera/driver/include -iwithprefix/espressif__esp32-camera/conversions/include -iwithprefix/driver/deprecated -iwithprefix/driver/i2c/include -iwithprefix/driver/touch_sensor/include -iwithprefix/driver/twai/include -iwithprefix/driver/touch_sensor/esp32/include -iwithprefix/esp_pm/include -iwithprefix/esp_ringbuf/include -iwithprefix/esp_driver_gpio/include -iwithprefix/esp_driver_pcnt/include -iwithprefix/esp_driver_gptimer/include -iwithprefix/esp_driver_spi/include -iwithprefix/esp_driver_mcpwm/include -iwithprefix/esp_driver_ana_cmpr/include -iwithprefix/esp_driver_i2s/include -iwithprefix/esp_driver_sdmmc/include -iwithprefix/sdmmc/include -iwithprefix/esp_driver_sdspi/include -iwithprefix/esp_driver_sdio/include -iwithprefix/esp_driver_dac/include -iwithprefix/esp_driver_rmt/include -iwithprefix/esp_driver_tsens/include -iwithprefix/esp_driver_sdm/include -iwithprefix/esp_driver_i2c/include -iwithprefix/esp_driver_uart/include -iwithprefix/vfs/include -iwithprefix/esp_driver_ledc/include -iwithprefix/esp_driver_parlio/include -iwithprefix/esp_driver_usb_serial_jtag/include -iwithprefix/espressif__esp_matter/connectedhomeip/connectedhomeip/src -iwithprefix/espressif__esp_matter/connectedhomeip/connectedhomeip/src/app/ember_coupling -iwithprefix/espressif__esp_matter/connectedhomeip/connectedhomeip/src/include -iwithprefix/espressif__esp_matter/connectedhomeip/connectedhomeip/src/lib -iwithprefix/espressif__esp_matter/connectedhomeip/connectedhomeip/src/lib/dnssd -iwithprefix/espressif__esp_matter/connectedhomeip/connectedhomeip/src/platform/OpenThread -iwithprefix/espressif__esp_matter/connectedhomeip/connectedhomeip/third_party/jsoncpp/repo/include -iwithprefix/espressif__esp_matter/connectedhomeip/connectedhomeip/third_party/nlfaultinjection/include -iwithprefix/espressif__esp_matter/connectedhomeip/connectedhomeip/third_party/nlassert/repo/include -iwithprefix/espressif__esp_matter/connectedhomeip/connectedhomeip/third_party/nlio/repo/include -iwithprefix/espressif__esp_matter/connectedhomeip/connectedhomeip/zzz_generated/app-common -iwithprefix/esp-idf/espressif__esp_matter -iwithprefix/esp_matter/zap_common -iwithprefix/esp_matter -iwithprefix/esp_matter/utils -iwithprefix/esp_matter_bridge -iwithprefix/esp_matter_console -iwithprefix/espressif__esp_matter/connectedhomeip/connectedhomeip/src/platform/ESP32 -iwithprefix/espressif__esp_matter/connectedhomeip/connectedhomeip/src/platform/ESP32/bluedroid -iwithprefix/espressif__esp_matter/connectedhomeip/connectedhomeip/src/platform/ESP32/nimble -iwithprefix/espressif__esp_matter/connectedhomeip/connectedhomeip/src/platform/ESP32/route_hook -iwithprefix/esp_eth/include -iwithprefix/esp_event/include -iwithprefix/bt/include/esp32/include -iwithprefix/bt/common/osi/include -iwithprefix/bt/common/api/include/api -iwithprefix/bt/common/btc/profile/esp/blufi/include -iwithprefix/bt/common/btc/profile/esp/include -iwithprefix/bt/common/hci_log/include -iwithprefix/bt/common/ble_log/include -iwithprefix/bt/host/bluedroid/api/include/api -iwithprefix/bt/esp_ble_mesh/common/include -iwithprefix/bt/esp_ble_mesh/common/tinycrypt/include -iwithprefix/bt/esp_ble_mesh/core -iwithprefix/bt/esp_ble_mesh/core/include -iwithprefix/bt/esp_ble_mesh/core/storage -iwithprefix/bt/esp_ble_mesh/btc/include -iwithprefix/bt/esp_ble_mesh/models/common/include -iwithprefix/bt/esp_ble_mesh/models/client/include -iwithprefix/bt/esp_ble_mesh/models/server/include -iwithprefix/bt/esp_ble_mesh/api/core/include -iwithprefix/bt/esp_ble_mesh/api/models/include -iwithprefix/bt/esp_ble_mesh/api -iwithprefix/bt/esp_ble_mesh/lib/include -iwithprefix/bt/esp_ble_mesh/v1.1/api/core/include -iwithprefix/bt/esp_ble_mesh/v1.1/api/models/include -iwithprefix/bt/esp_ble_mesh/v1.1/btc/include -iwithprefix/bt/porting/ext/tinycrypt/include -iwithprefix/esp_wifi/include -iwithprefix/esp_wifi/include/local -iwithprefix/esp_wifi/wifi_apps/include -iwithprefix/esp_wifi/wifi_apps/nan_app/include -iwithprefix/esp_phy/include -iwithprefix/esp_phy/esp32/include -iwithprefix/esp_netif/include -iwithprefix/mbedtls/port/include -iwithprefix/mbedtls/mbedtls/include -iwithprefix/mbedtls/mbedtls/library -iwithprefix/mbedtls/esp_crt_bundle/include -iwithprefix/mbedtls/mbedtls/3rdparty/everest/include -iwithprefix/mbedtls/mbedtls/3rdparty/p256-m -iwithprefix/mbedtls/mbedtls/3rdparty/p256-m/p256-m -iwithprefix/fatfs/diskio -iwithprefix/fatfs/src -iwithprefix/fatfs/vfs -iwithprefix/wear_levelling/include -iwithprefix/esp_partition/include -iwithprefix/app_update/include -iwithprefix/bootloader_support/include -iwithprefix/bootloader_support/bootloader_flash/include -iwithprefix/esp_app_format/include -iwithprefix/esp_bootloader_format/include -iwithprefix/console -iwithprefix/esp_vfs_console/include -iwithprefix/openthread/include -iwithprefix/openthread/openthread/include -iwithprefix/nvs_flash/include -iwithprefix/spi_flash/include -iwithprefix/espressif__esp_secure_cert_mgr/include -iwithprefix/efuse/include -iwithprefix/efuse/esp32/include -iwithprefix/espressif__json_parser/include -iwithprefix/espressif__jsmn/include -iwithprefix/spiffs/include -iwithprefix/esp_http_client/include -iwithprefix/espressif__json_generator/include -iwithprefix/json/cJSON -iwithprefix/espressif__mdns/include -iwithprefix/espressif__esp_delta_ota/include -iwithprefix/espressif__esp_encrypted_img/include -iwithprefix/espressif__esp_insights/include -iwithprefix/espressif__esp_diagnostics/include -iwithprefix/esp_mm/include -iwithprefix/esp_security/include -iwithprefix/pthread/include -iwithprefix/app_trace/include -iwithprefix/wpa_supplicant/include -iwithprefix/wpa_supplicant/port/include -iwithprefix/wpa_supplicant/esp_supplicant/include -iwithprefix/esp_coex/include -iwithprefix/unity/include -iwithprefix/unity/unity/src -iwithprefix/cmock/CMock/src -iwithprefix/http_parser -iwithprefix/esp-tls -iwithprefix/esp-tls/esp-tls-crypto -iwithprefix/esp_adc/include -iwithprefix/esp_adc/interface -iwithprefix/esp_adc/esp32/include -iwithprefix/esp_adc/deprecated/include -iwithprefix/esp_driver_isp/include -iwithprefix/esp_driver_cam/include -iwithprefix/esp_driver_cam/interface -iwithprefix/esp_driver_jpeg/include -iwithprefix/esp_driver_ppa/include -iwithprefix/esp_gdbstub/include -iwithprefix/esp_hid/include -iwithprefix/tcp_transport/include -iwithprefix/esp_http_server/include -iwithprefix/esp_https_ota/include -iwithprefix/esp_https_server/include -iwithprefix/esp_psram/include -iwithprefix/esp_lcd/include -iwithprefix/esp_lcd/interface -iwithprefix/protobuf-c/protobuf-c -iwithprefix/protocomm/include/common -iwithprefix/protocomm/include/security -iwithprefix/protocomm/include/transports -iwithprefix/protocomm/include/crypto/srp6a -iwithprefix/protocomm/proto-c -iwithprefix/esp_local_ctrl/include -iwithprefix/espcoredump/include -iwithprefix/espcoredump/include/port/xtensa -iwithprefix/idf_test/include -iwithprefix/idf_test/include/esp32 -iwithprefix/ieee802154/include -iwithprefix/mqtt/esp-mqtt/include -iwithprefix/nvs_sec_provider/include -iwithprefix/perfmon/include -iwithprefix/rt/include -iwithprefix/ulp/ulp_common/include -iwithprefix/ulp/ulp_fsm/include -iwithprefix/ulp/ulp_fsm/include/esp32 -iwithprefix/wifi_provisioning/include -iwithprefix/espressif__esp-nn/include -iwithprefix/espressif__esp-nn/src/common -iwithprefix/espressif__rmaker_common/include -iwithprefix/espressif__cbor/port/include -iwithprefix/espressif__esp_diag_data_store/src/rtc_store -iwithprefix/espressif__esp_diag_data_store/include -iwithprefix/espressif__esp-serial-flasher/include -iwithprefix/espressif__esp-serial-flasher/port -iwithprefix/espressif__esp_rcp_update/include -iwithprefix/chmorgan__esp-libhelix-mp3/libhelix-mp3/pub -iwithprefix/espressif__esp-modbus/freemodbus/common/include -iwithprefix/espressif__esp-zboss-lib/include -iwithprefix/espressif__esp-zigbee-lib/include -iwithprefix/espressif__esp-zigbee-lib/include/radio_spinel -iwithprefix/espressif__libsodium/libsodium/src/libsodium/include -iwithprefix/espressif__libsodium/port_include -iwithprefix/espressif__esp-dsp/modules/dotprod/include -iwithprefix/espressif__esp-dsp/modules/support/include -iwithprefix/espressif__esp-dsp/modules/support/mem/include -iwithprefix/espressif__esp-dsp/modules/windows/include -iwithprefix/espressif__esp-dsp/modules/windows/hann/include -iwithprefix/espressif__esp-dsp/modules/windows/blackman/include -iwithprefix/espressif__esp-dsp/modules/windows/blackman_harris/include -iwithprefix/espressif__esp-dsp/modules/windows/blackman_nuttall/include -iwithprefix/espressif__esp-dsp/modules/windows/nuttall/include -iwithprefix/espressif__esp-dsp/modules/windows/flat_top/include -iwithprefix/espressif__esp-dsp/modules/iir/include -iwithprefix/espressif__esp-dsp/modules/fir/include -iwithprefix/espressif__esp-dsp/modules/math/include -iwithprefix/espressif__esp-dsp/modules/math/add/include -iwithprefix/espressif__esp-dsp/modules/math/sub/include -iwithprefix/espressif__esp-dsp/modules/math/mul/include -iwithprefix/espressif__esp-dsp/modules/math/addc/include -iwithprefix/espressif__esp-dsp/modules/math/mulc/include -iwithprefix/espressif__esp-dsp/modules/math/sqrt/include -iwithprefix/espressif__esp-dsp/modules/matrix/mul/include -iwithprefix/espressif__esp-dsp/modules/matrix/add/include -iwithprefix/espressif__esp-dsp/modules/matrix/addc/include -iwithprefix/espressif__esp-dsp/modules/matrix/mulc/include -iwithprefix/espressif__esp-dsp/modules/matrix/sub/include -iwithprefix/espressif__esp-dsp/modules/matrix/include -iwithprefix/espressif__esp-dsp/modules/fft/include -iwithprefix/espressif__esp-dsp/modules/dct/include -iwithprefix/espressif__esp-dsp/modules/conv/include -iwithprefix/espressif__esp-dsp/modules/common/include -iwithprefix/espressif__esp-dsp/modules/matrix/mul/test/include -iwithprefix/espressif__esp-dsp/modules/kalman/ekf/include -iwithprefix/espressif__esp-dsp/modules/kalman/ekf_imu13states/include -iwithprefix/espressif__esp_modem/include -iwithprefix/espressif__esp_schedule/include -iwithprefix/espressif__network_provisioning/include -iwithprefix/espressif__esp_rainmaker/include -iwithprefix/espressif__qrcode/include -iwithprefix/joltwallet__littlefs/include -iwithprefix/fb_gfx/include -DPLATFORMIO=60118 -DARDUINO_ESP32_DEV -DESP32_ARDUINO_LIB_BUILDER -DESP_MDNS_VERSION_NUMBER=\"1.8.2\" -DESP_PLATFORM -DIDF_VER=\"v5.4.1-1-g2f7dcd862a-dirty\" -DMBEDTLS_CONFIG_FILE=\"mbedtls/esp_config.h\" -DMD5_ENABLED=1 -DOPENTHREAD_CONFIG_FILE=\"openthread-core-esp32x-spinel-config.h\" -DOPENTHREAD_PROJECT_LIB_CONFIG_FILE=\"openthread-core-esp32x-spinel-config.h\" -DSERIAL_FLASHER_BOOT_HOLD_TIME_MS=50 -DSERIAL_FLASHER_RESET_HOLD_TIME_MS=100 -DSOC_MMU_PAGE_SIZE=CONFIG_MMU_PAGE_SIZE -DSOC_XTAL_FREQ_MHZ=CONFIG_XTAL_FREQ -DUNITY_INCLUDE_CONFIG_H -D_GLIBCXX_HAVE_POSIX_SEMAPHORE -D_GLIBCXX_USE_POSIX_SEMAPHORE -D_GNU_SOURCE -D_POSIX_READER_WRITER_LOCKS -DTF_LITE_STATIC_MEMORY -DCHIP_CONFIG_SOFTWARE_VERSION_NUMBER=0 -DNDEBUG -DCHIP_MINMDNS_DEFAULT_POLICY=1 -DCHIP_MINMDNS_USE_EPHEMERAL_UNICAST_PORT=0 -DCHIP_MINMDNS_HIGH_VERBOSITY=0 -DCHIP_DNSSD_DEFAULT_MINIMAL=true -DCHIP_DNSSD_DEFAULT_NONE=false -DCHIP_DNSSD_DEFAULT_PLATFORM=false -DARDUINO_ARCH_ESP32 -DCHIP_HAVE_CONFIG_H -DESP32=ESP32 -DF_CPU=240000000L -DARDUINO=10812 -DARDUINO_VARIANT=\"doitESP32devkitV1\" "-DARDUINO_BOARD=\"DOIT ESP32 DEVKIT V1\"" -DARDUINO_PARTITION_default -I.pio/libdeps/esp32doit-devkit-v1/ESPAsyncWebServer/src -IC:/.platformio/packages/framework-arduinoespressif32/libraries/FS/src -I.pio/libdeps/esp32doit-devkit-v1/ArduinoJson/src "-I.pio/libdeps/esp32doit-devkit-v1/Async TCP/src" -IC:/.platformio/packages/framework-arduinoespressif32/libraries/WiFi/src -IC:/.platformio/packages/framework-arduinoespressif32/libraries/Network/src -IC:/.platformio/packages/framework-arduinoespressif32-libs/esp32/dio_qspi/include -IC:/.platformio/packages/framework-arduinoespressif32/cores/esp32 -IC:/.platformio/packages/framework-arduinoespressif32/variants/doitESP32devkitV1 .pio/libdeps/esp32doit-devkit-v1/ESPAsyncWebServer/src/AsyncJson.cpp
xtensa-esp32-elf-g++ "@E:\My Drive\OpenHaldex\Can2Cluster\.pio\build\esp32doit-devkit-v1\tmp7o1hnwga.tmp"
Using tempfile E:\My Drive\OpenHaldex\Can2Cluster\.pio\build\esp32doit-devkit-v1\tmpltjmdb6o.tmp for command line:
xtensa-esp32-elf-g++ -o .pio/build/esp32doit-devkit-v1/libf48/ESPAsyncWebServer/AsyncWebHeader.cpp.o -c -Wno-frame-address -fno-builtin-memcpy -fno-builtin-memset -fno-builtin-bzero -fno-builtin-stpcpy -fno-builtin-strncpy -std=gnu++2b -fexceptions -fno-rtti -fuse-cxa-atexit -std=gnu++2a -Werror=return-type -Os -mlongcalls -ffunction-sections -fdata-sections -Wno-error=unused-function -Wno-error=unused-variable -Wno-error=unused-but-set-variable -Wno-error=deprecated-declarations -Wno-error=extra -Wno-unused-parameter -Wno-sign-compare -Wno-enum-conversion -gdwarf-4 -ggdb -mdisable-hardware-atomics -freorder-blocks -Wwrite-strings -fstack-protector -fstrict-volatile-bitfields -fno-jump-tables -fno-tree-switch-conversion "-DCHIP_ADDRESS_RESOLVE_IMPL_INCLUDE_HEADER=<lib/address_resolve/AddressResolve_DefaultImpl.h>" -MMD -iprefix C:/.platformio/packages/framework-arduinoespressif32-libs/esp32/include -iwithprefix/newlib/platform_include -iwithprefix/freertos/config/include -iwithprefix/freertos/config/include/freertos -iwithprefix/freertos/config/xtensa/include -iwithprefix/freertos/FreeRTOS-Kernel/include -iwithprefix/freertos/FreeRTOS-Kernel/portable/xtensa/include -iwithprefix/freertos/FreeRTOS-Kernel/portable/xtensa/include/freertos -iwithprefix/freertos/esp_additions/include -iwithprefix/esp_hw_support/include -iwithprefix/esp_hw_support/include/soc -iwithprefix/esp_hw_support/include/soc/esp32 -iwithprefix/esp_hw_support/dma/include -iwithprefix/esp_hw_support/ldo/include -iwithprefix/esp_hw_support/debug_probe/include -iwithprefix/esp_hw_support/port/esp32 -iwithprefix/esp_hw_support/port/esp32/include -iwithprefix/heap/include -iwithprefix/heap/tlsf -iwithprefix/log/include -iwithprefix/soc/include -iwithprefix/soc/esp32 -iwithprefix/soc/esp32/include -iwithprefix/soc/esp32/register -iwithprefix/hal/platform_port/include -iwithprefix/hal/esp32/include -iwithprefix/hal/include -iwithprefix/esp_rom/include -iwithprefix/esp_rom/esp32/include -iwithprefix/esp_rom/esp32/include/esp32 -iwithprefix/esp_rom/esp32 -iwithprefix/esp_common/include -iwithprefix/esp_system/include -iwithprefix/esp_system/port/soc -iwithprefix/esp_system/port/include/private -iwithprefix/xtensa/esp32/include -iwithprefix/xtensa/include -iwithprefix/xtensa/deprecated_include -iwithprefix/esp_timer/include -iwithprefix/lwip/include -iwithprefix/lwip/include/apps -iwithprefix/lwip/include/apps/sntp -iwithprefix/lwip/lwip/src/include -iwithprefix/lwip/port/include -iwithprefix/lwip/port/freertos/include -iwithprefix/lwip/port/esp32xx/include -iwithprefix/lwip/port/esp32xx/include/arch -iwithprefix/lwip/port/esp32xx/include/sys -iwithprefix/espressif__esp-tflite-micro -iwithprefix/espressif__esp-tflite-micro/third_party/gemmlowp -iwithprefix/espressif__esp-tflite-micro/third_party/flatbuffers/include -iwithprefix/espressif__esp-tflite-micro/third_party/ruy -iwithprefix/espressif__esp-tflite-micro/third_party/kissfft -iwithprefix/espressif__esp32-camera/driver/include -iwithprefix/espressif__esp32-camera/conversions/include -iwithprefix/driver/deprecated -iwithprefix/driver/i2c/include -iwithprefix/driver/touch_sensor/include -iwithprefix/driver/twai/include -iwithprefix/driver/touch_sensor/esp32/include -iwithprefix/esp_pm/include -iwithprefix/esp_ringbuf/include -iwithprefix/esp_driver_gpio/include -iwithprefix/esp_driver_pcnt/include -iwithprefix/esp_driver_gptimer/include -iwithprefix/esp_driver_spi/include -iwithprefix/esp_driver_mcpwm/include -iwithprefix/esp_driver_ana_cmpr/include -iwithprefix/esp_driver_i2s/include -iwithprefix/esp_driver_sdmmc/include -iwithprefix/sdmmc/include -iwithprefix/esp_driver_sdspi/include -iwithprefix/esp_driver_sdio/include -iwithprefix/esp_driver_dac/include -iwithprefix/esp_driver_rmt/include -iwithprefix/esp_driver_tsens/include -iwithprefix/esp_driver_sdm/include -iwithprefix/esp_driver_i2c/include -iwithprefix/esp_driver_uart/include -iwithprefix/vfs/include -iwithprefix/esp_driver_ledc/include -iwithprefix/esp_driver_parlio/include -iwithprefix/esp_driver_usb_serial_jtag/include -iwithprefix/espressif__esp_matter/connectedhomeip/connectedhomeip/src -iwithprefix/espressif__esp_matter/connectedhomeip/connectedhomeip/src/app/ember_coupling -iwithprefix/espressif__esp_matter/connectedhomeip/connectedhomeip/src/include -iwithprefix/espressif__esp_matter/connectedhomeip/connectedhomeip/src/lib -iwithprefix/espressif__esp_matter/connectedhomeip/connectedhomeip/src/lib/dnssd -iwithprefix/espressif__esp_matter/connectedhomeip/connectedhomeip/src/platform/OpenThread -iwithprefix/espressif__esp_matter/connectedhomeip/connectedhomeip/third_party/jsoncpp/repo/include -iwithprefix/espressif__esp_matter/connectedhomeip/connectedhomeip/third_party/nlfaultinjection/include -iwithprefix/espressif__esp_matter/connectedhomeip/connectedhomeip/third_party/nlassert/repo/include -iwithprefix/espressif__esp_matter/connectedhomeip/connectedhomeip/third_party/nlio/repo/include -iwithprefix/espressif__esp_matter/connectedhomeip/connectedhomeip/zzz_generated/app-common -iwithprefix/esp-idf/espressif__esp_matter -iwithprefix/esp_matter/zap_common -iwithprefix/esp_matter -iwithprefix/esp_matter/utils -iwithprefix/esp_matter_bridge -iwithprefix/esp_matter_console -iwithprefix/espressif__esp_matter/connectedhomeip/connectedhomeip/src/platform/ESP32 -iwithprefix/espressif__esp_matter/connectedhomeip/connectedhomeip/src/platform/ESP32/bluedroid -iwithprefix/espressif__esp_matter/connectedhomeip/connectedhomeip/src/platform/ESP32/nimble -iwithprefix/espressif__esp_matter/connectedhomeip/connectedhomeip/src/platform/ESP32/route_hook -iwithprefix/esp_eth/include -iwithprefix/esp_event/include -iwithprefix/bt/include/esp32/include -iwithprefix/bt/common/osi/include -iwithprefix/bt/common/api/include/api -iwithprefix/bt/common/btc/profile/esp/blufi/include -iwithprefix/bt/common/btc/profile/esp/include -iwithprefix/bt/common/hci_log/include -iwithprefix/bt/common/ble_log/include -iwithprefix/bt/host/bluedroid/api/include/api -iwithprefix/bt/esp_ble_mesh/common/include -iwithprefix/bt/esp_ble_mesh/common/tinycrypt/include -iwithprefix/bt/esp_ble_mesh/core -iwithprefix/bt/esp_ble_mesh/core/include -iwithprefix/bt/esp_ble_mesh/core/storage -iwithprefix/bt/esp_ble_mesh/btc/include -iwithprefix/bt/esp_ble_mesh/models/common/include -iwithprefix/bt/esp_ble_mesh/models/client/include -iwithprefix/bt/esp_ble_mesh/models/server/include -iwithprefix/bt/esp_ble_mesh/api/core/include -iwithprefix/bt/esp_ble_mesh/api/models/include -iwithprefix/bt/esp_ble_mesh/api -iwithprefix/bt/esp_ble_mesh/lib/include -iwithprefix/bt/esp_ble_mesh/v1.1/api/core/include -iwithprefix/bt/esp_ble_mesh/v1.1/api/models/include -iwithprefix/bt/esp_ble_mesh/v1.1/btc/include -iwithprefix/bt/porting/ext/tinycrypt/include -iwithprefix/esp_wifi/include -iwithprefix/esp_wifi/include/local -iwithprefix/esp_wifi/wifi_apps/include -iwithprefix/esp_wifi/wifi_apps/nan_app/include -iwithprefix/esp_phy/include -iwithprefix/esp_phy/esp32/include -iwithprefix/esp_netif/include -iwithprefix/mbedtls/port/include -iwithprefix/mbedtls/mbedtls/include -iwithprefix/mbedtls/mbedtls/library -iwithprefix/mbedtls/esp_crt_bundle/include -iwithprefix/mbedtls/mbedtls/3rdparty/everest/include -iwithprefix/mbedtls/mbedtls/3rdparty/p256-m -iwithprefix/mbedtls/mbedtls/3rdparty/p256-m/p256-m -iwithprefix/fatfs/diskio -iwithprefix/fatfs/src -iwithprefix/fatfs/vfs -iwithprefix/wear_levelling/include -iwithprefix/esp_partition/include -iwithprefix/app_update/include -iwithprefix/bootloader_support/include -iwithprefix/bootloader_support/bootloader_flash/include -iwithprefix/esp_app_format/include -iwithprefix/esp_bootloader_format/include -iwithprefix/console -iwithprefix/esp_vfs_console/include -iwithprefix/openthread/include -iwithprefix/openthread/openthread/include -iwithprefix/nvs_flash/include -iwithprefix/spi_flash/include -iwithprefix/espressif__esp_secure_cert_mgr/include -iwithprefix/efuse/include -iwithprefix/efuse/esp32/include -iwithprefix/espressif__json_parser/include -iwithprefix/espressif__jsmn/include -iwithprefix/spiffs/include -iwithprefix/esp_http_client/include -iwithprefix/espressif__json_generator/include -iwithprefix/json/cJSON -iwithprefix/espressif__mdns/include -iwithprefix/espressif__esp_delta_ota/include -iwithprefix/espressif__esp_encrypted_img/include -iwithprefix/espressif__esp_insights/include -iwithprefix/espressif__esp_diagnostics/include -iwithprefix/esp_mm/include -iwithprefix/esp_security/include -iwithprefix/pthread/include -iwithprefix/app_trace/include -iwithprefix/wpa_supplicant/include -iwithprefix/wpa_supplicant/port/include -iwithprefix/wpa_supplicant/esp_supplicant/include -iwithprefix/esp_coex/include -iwithprefix/unity/include -iwithprefix/unity/unity/src -iwithprefix/cmock/CMock/src -iwithprefix/http_parser -iwithprefix/esp-tls -iwithprefix/esp-tls/esp-tls-crypto -iwithprefix/esp_adc/include -iwithprefix/esp_adc/interface -iwithprefix/esp_adc/esp32/include -iwithprefix/esp_adc/deprecated/include -iwithprefix/esp_driver_isp/include -iwithprefix/esp_driver_cam/include -iwithprefix/esp_driver_cam/interface -iwithprefix/esp_driver_jpeg/include -iwithprefix/esp_driver_ppa/include -iwithprefix/esp_gdbstub/include -iwithprefix/esp_hid/include -iwithprefix/tcp_transport/include -iwithprefix/esp_http_server/include -iwithprefix/esp_https_ota/include -iwithprefix/esp_https_server/include -iwithprefix/esp_psram/include -iwithprefix/esp_lcd/include -iwithprefix/esp_lcd/interface -iwithprefix/protobuf-c/protobuf-c -iwithprefix/protocomm/include/common -iwithprefix/protocomm/include/security -iwithprefix/protocomm/include/transports -iwithprefix/protocomm/include/crypto/srp6a -iwithprefix/protocomm/proto-c -iwithprefix/esp_local_ctrl/include -iwithprefix/espcoredump/include -iwithprefix/espcoredump/include/port/xtensa -iwithprefix/idf_test/include -iwithprefix/idf_test/include/esp32 -iwithprefix/ieee802154/include -iwithprefix/mqtt/esp-mqtt/include -iwithprefix/nvs_sec_provider/include -iwithprefix/perfmon/include -iwithprefix/rt/include -iwithprefix/ulp/ulp_common/include -iwithprefix/ulp/ulp_fsm/include -iwithprefix/ulp/ulp_fsm/include/esp32 -iwithprefix/wifi_provisioning/include -iwithprefix/espressif__esp-nn/include -iwithprefix/espressif__esp-nn/src/common -iwithprefix/espressif__rmaker_common/include -iwithprefix/espressif__cbor/port/include -iwithprefix/espressif__esp_diag_data_store/src/rtc_store -iwithprefix/espressif__esp_diag_data_store/include -iwithprefix/espressif__esp-serial-flasher/include -iwithprefix/espressif__esp-serial-flasher/port -iwithprefix/espressif__esp_rcp_update/include -iwithprefix/chmorgan__esp-libhelix-mp3/libhelix-mp3/pub -iwithprefix/espressif__esp-modbus/freemodbus/common/include -iwithprefix/espressif__esp-zboss-lib/include -iwithprefix/espressif__esp-zigbee-lib/include -iwithprefix/espressif__esp-zigbee-lib/include/radio_spinel -iwithprefix/espressif__libsodium/libsodium/src/libsodium/include -iwithprefix/espressif__libsodium/port_include -iwithprefix/espressif__esp-dsp/modules/dotprod/include -iwithprefix/espressif__esp-dsp/modules/support/include -iwithprefix/espressif__esp-dsp/modules/support/mem/include -iwithprefix/espressif__esp-dsp/modules/windows/include -iwithprefix/espressif__esp-dsp/modules/windows/hann/include -iwithprefix/espressif__esp-dsp/modules/windows/blackman/include -iwithprefix/espressif__esp-dsp/modules/windows/blackman_harris/include -iwithprefix/espressif__esp-dsp/modules/windows/blackman_nuttall/include -iwithprefix/espressif__esp-dsp/modules/windows/nuttall/include -iwithprefix/espressif__esp-dsp/modules/windows/flat_top/include -iwithprefix/espressif__esp-dsp/modules/iir/include -iwithprefix/espressif__esp-dsp/modules/fir/include -iwithprefix/espressif__esp-dsp/modules/math/include -iwithprefix/espressif__esp-dsp/modules/math/add/include -iwithprefix/espressif__esp-dsp/modules/math/sub/include -iwithprefix/espressif__esp-dsp/modules/math/mul/include -iwithprefix/espressif__esp-dsp/modules/math/addc/include -iwithprefix/espressif__esp-dsp/modules/math/mulc/include -iwithprefix/espressif__esp-dsp/modules/math/sqrt/include -iwithprefix/espressif__esp-dsp/modules/matrix/mul/include -iwithprefix/espressif__esp-dsp/modules/matrix/add/include -iwithprefix/espressif__esp-dsp/modules/matrix/addc/include -iwithprefix/espressif__esp-dsp/modules/matrix/mulc/include -iwithprefix/espressif__esp-dsp/modules/matrix/sub/include -iwithprefix/espressif__esp-dsp/modules/matrix/include -iwithprefix/espressif__esp-dsp/modules/fft/include -iwithprefix/espressif__esp-dsp/modules/dct/include -iwithprefix/espressif__esp-dsp/modules/conv/include -iwithprefix/espressif__esp-dsp/modules/common/include -iwithprefix/espressif__esp-dsp/modules/matrix/mul/test/include -iwithprefix/espressif__esp-dsp/modules/kalman/ekf/include -iwithprefix/espressif__esp-dsp/modules/kalman/ekf_imu13states/include -iwithprefix/espressif__esp_modem/include -iwithprefix/espressif__esp_schedule/include -iwithprefix/espressif__network_provisioning/include -iwithprefix/espressif__esp_rainmaker/include -iwithprefix/espressif__qrcode/include -iwithprefix/joltwallet__littlefs/include -iwithprefix/fb_gfx/include -DPLATFORMIO=60118 -DARDUINO_ESP32_DEV -DESP32_ARDUINO_LIB_BUILDER -DESP_MDNS_VERSION_NUMBER=\"1.8.2\" -DESP_PLATFORM -DIDF_VER=\"v5.4.1-1-g2f7dcd862a-dirty\" -DMBEDTLS_CONFIG_FILE=\"mbedtls/esp_config.h\" -DMD5_ENABLED=1 -DOPENTHREAD_CONFIG_FILE=\"openthread-core-esp32x-spinel-config.h\" -DOPENTHREAD_PROJECT_LIB_CONFIG_FILE=\"openthread-core-esp32x-spinel-config.h\" -DSERIAL_FLASHER_BOOT_HOLD_TIME_MS=50 -DSERIAL_FLASHER_RESET_HOLD_TIME_MS=100 -DSOC_MMU_PAGE_SIZE=CONFIG_MMU_PAGE_SIZE -DSOC_XTAL_FREQ_MHZ=CONFIG_XTAL_FREQ -DUNITY_INCLUDE_CONFIG_H -D_GLIBCXX_HAVE_POSIX_SEMAPHORE -D_GLIBCXX_USE_POSIX_SEMAPHORE -D_GNU_SOURCE -D_POSIX_READER_WRITER_LOCKS -DTF_LITE_STATIC_MEMORY -DCHIP_CONFIG_SOFTWARE_VERSION_NUMBER=0 -DNDEBUG -DCHIP_MINMDNS_DEFAULT_POLICY=1 -DCHIP_MINMDNS_USE_EPHEMERAL_UNICAST_PORT=0 -DCHIP_MINMDNS_HIGH_VERBOSITY=0 -DCHIP_DNSSD_DEFAULT_MINIMAL=true -DCHIP_DNSSD_DEFAULT_NONE=false -DCHIP_DNSSD_DEFAULT_PLATFORM=false -DARDUINO_ARCH_ESP32 -DCHIP_HAVE_CONFIG_H -DESP32=ESP32 -DF_CPU=240000000L -DARDUINO=10812 -DARDUINO_VARIANT=\"doitESP32devkitV1\" "-DARDUINO_BOARD=\"DOIT ESP32 DEVKIT V1\"" -DARDUINO_PARTITION_default -I.pio/libdeps/esp32doit-devkit-v1/ESPAsyncWebServer/src -IC:/.platformio/packages/framework-arduinoespressif32/libraries/FS/src -I.pio/libdeps/esp32doit-devkit-v1/ArduinoJson/src "-I.pio/libdeps/esp32doit-devkit-v1/Async TCP/src" -IC:/.platformio/packages/framework-arduinoespressif32/libraries/WiFi/src -IC:/.platformio/packages/framework-arduinoespressif32/libraries/Network/src -IC:/.platformio/packages/framework-arduinoespressif32-libs/esp32/dio_qspi/include -IC:/.platformio/packages/framework-arduinoespressif32/cores/esp32 -IC:/.platformio/packages/framework-arduinoespressif32/variants/doitESP32devkitV1 .pio/libdeps/esp32doit-devkit-v1/ESPAsyncWebServer/src/AsyncWebHeader.cpp
xtensa-esp32-elf-g++ "@E:\My Drive\OpenHaldex\Can2Cluster\.pio\build\esp32doit-devkit-v1\tmpltjmdb6o.tmp"
Using tempfile E:\My Drive\OpenHaldex\Can2Cluster\.pio\build\esp32doit-devkit-v1\tmp6vwye_2l.tmp for command line:
xtensa-esp32-elf-g++ -o .pio/build/esp32doit-devkit-v1/libf48/ESPAsyncWebServer/AsyncWebServerRequest.cpp.o -c -Wno-frame-address -fno-builtin-memcpy -fno-builtin-memset -fno-builtin-bzero -fno-builtin-stpcpy -fno-builtin-strncpy -std=gnu++2b -fexceptions -fno-rtti -fuse-cxa-atexit -std=gnu++2a -Werror=return-type -Os -mlongcalls -ffunction-sections -fdata-sections -Wno-error=unused-function -Wno-error=unused-variable -Wno-error=unused-but-set-variable -Wno-error=deprecated-declarations -Wno-error=extra -Wno-unused-parameter -Wno-sign-compare -Wno-enum-conversion -gdwarf-4 -ggdb -mdisable-hardware-atomics -freorder-blocks -Wwrite-strings -fstack-protector -fstrict-volatile-bitfields -fno-jump-tables -fno-tree-switch-conversion "-DCHIP_ADDRESS_RESOLVE_IMPL_INCLUDE_HEADER=<lib/address_resolve/AddressResolve_DefaultImpl.h>" -MMD -iprefix C:/.platformio/packages/framework-arduinoespressif32-libs/esp32/include -iwithprefix/newlib/platform_include -iwithprefix/freertos/config/include -iwithprefix/freertos/config/include/freertos -iwithprefix/freertos/config/xtensa/include -iwithprefix/freertos/FreeRTOS-Kernel/include -iwithprefix/freertos/FreeRTOS-Kernel/portable/xtensa/include -iwithprefix/freertos/FreeRTOS-Kernel/portable/xtensa/include/freertos -iwithprefix/freertos/esp_additions/include -iwithprefix/esp_hw_support/include -iwithprefix/esp_hw_support/include/soc -iwithprefix/esp_hw_support/include/soc/esp32 -iwithprefix/esp_hw_support/dma/include -iwithprefix/esp_hw_support/ldo/include -iwithprefix/esp_hw_support/debug_probe/include -iwithprefix/esp_hw_support/port/esp32 -iwithprefix/esp_hw_support/port/esp32/include -iwithprefix/heap/include -iwithprefix/heap/tlsf -iwithprefix/log/include -iwithprefix/soc/include -iwithprefix/soc/esp32 -iwithprefix/soc/esp32/include -iwithprefix/soc/esp32/register -iwithprefix/hal/platform_port/include -iwithprefix/hal/esp32/include -iwithprefix/hal/include -iwithprefix/esp_rom/include -iwithprefix/esp_rom/esp32/include -iwithprefix/esp_rom/esp32/include/esp32 -iwithprefix/esp_rom/esp32 -iwithprefix/esp_common/include -iwithprefix/esp_system/include -iwithprefix/esp_system/port/soc -iwithprefix/esp_system/port/include/private -iwithprefix/xtensa/esp32/include -iwithprefix/xtensa/include -iwithprefix/xtensa/deprecated_include -iwithprefix/esp_timer/include -iwithprefix/lwip/include -iwithprefix/lwip/include/apps -iwithprefix/lwip/include/apps/sntp -iwithprefix/lwip/lwip/src/include -iwithprefix/lwip/port/include -iwithprefix/lwip/port/freertos/include -iwithprefix/lwip/port/esp32xx/include -iwithprefix/lwip/port/esp32xx/include/arch -iwithprefix/lwip/port/esp32xx/include/sys -iwithprefix/espressif__esp-tflite-micro -iwithprefix/espressif__esp-tflite-micro/third_party/gemmlowp -iwithprefix/espressif__esp-tflite-micro/third_party/flatbuffers/include -iwithprefix/espressif__esp-tflite-micro/third_party/ruy -iwithprefix/espressif__esp-tflite-micro/third_party/kissfft -iwithprefix/espressif__esp32-camera/driver/include -iwithprefix/espressif__esp32-camera/conversions/include -iwithprefix/driver/deprecated -iwithprefix/driver/i2c/include -iwithprefix/driver/touch_sensor/include -iwithprefix/driver/twai/include -iwithprefix/driver/touch_sensor/esp32/include -iwithprefix/esp_pm/include -iwithprefix/esp_ringbuf/include -iwithprefix/esp_driver_gpio/include -iwithprefix/esp_driver_pcnt/include -iwithprefix/esp_driver_gptimer/include -iwithprefix/esp_driver_spi/include -iwithprefix/esp_driver_mcpwm/include -iwithprefix/esp_driver_ana_cmpr/include -iwithprefix/esp_driver_i2s/include -iwithprefix/esp_driver_sdmmc/include -iwithprefix/sdmmc/include -iwithprefix/esp_driver_sdspi/include -iwithprefix/esp_driver_sdio/include -iwithprefix/esp_driver_dac/include -iwithprefix/esp_driver_rmt/include -iwithprefix/esp_driver_tsens/include -iwithprefix/esp_driver_sdm/include -iwithprefix/esp_driver_i2c/include -iwithprefix/esp_driver_uart/include -iwithprefix/vfs/include -iwithprefix/esp_driver_ledc/include -iwithprefix/esp_driver_parlio/include -iwithprefix/esp_driver_usb_serial_jtag/include -iwithprefix/espressif__esp_matter/connectedhomeip/connectedhomeip/src -iwithprefix/espressif__esp_matter/connectedhomeip/connectedhomeip/src/app/ember_coupling -iwithprefix/espressif__esp_matter/connectedhomeip/connectedhomeip/src/include -iwithprefix/espressif__esp_matter/connectedhomeip/connectedhomeip/src/lib -iwithprefix/espressif__esp_matter/connectedhomeip/connectedhomeip/src/lib/dnssd -iwithprefix/espressif__esp_matter/connectedhomeip/connectedhomeip/src/platform/OpenThread -iwithprefix/espressif__esp_matter/connectedhomeip/connectedhomeip/third_party/jsoncpp/repo/include -iwithprefix/espressif__esp_matter/connectedhomeip/connectedhomeip/third_party/nlfaultinjection/include -iwithprefix/espressif__esp_matter/connectedhomeip/connectedhomeip/third_party/nlassert/repo/include -iwithprefix/espressif__esp_matter/connectedhomeip/connectedhomeip/third_party/nlio/repo/include -iwithprefix/espressif__esp_matter/connectedhomeip/connectedhomeip/zzz_generated/app-common -iwithprefix/esp-idf/espressif__esp_matter -iwithprefix/esp_matter/zap_common -iwithprefix/esp_matter -iwithprefix/esp_matter/utils -iwithprefix/esp_matter_bridge -iwithprefix/esp_matter_console -iwithprefix/espressif__esp_matter/connectedhomeip/connectedhomeip/src/platform/ESP32 -iwithprefix/espressif__esp_matter/connectedhomeip/connectedhomeip/src/platform/ESP32/bluedroid -iwithprefix/espressif__esp_matter/connectedhomeip/connectedhomeip/src/platform/ESP32/nimble -iwithprefix/espressif__esp_matter/connectedhomeip/connectedhomeip/src/platform/ESP32/route_hook -iwithprefix/esp_eth/include -iwithprefix/esp_event/include -iwithprefix/bt/include/esp32/include -iwithprefix/bt/common/osi/include -iwithprefix/bt/common/api/include/api -iwithprefix/bt/common/btc/profile/esp/blufi/include -iwithprefix/bt/common/btc/profile/esp/include -iwithprefix/bt/common/hci_log/include -iwithprefix/bt/common/ble_log/include -iwithprefix/bt/host/bluedroid/api/include/api -iwithprefix/bt/esp_ble_mesh/common/include -iwithprefix/bt/esp_ble_mesh/common/tinycrypt/include -iwithprefix/bt/esp_ble_mesh/core -iwithprefix/bt/esp_ble_mesh/core/include -iwithprefix/bt/esp_ble_mesh/core/storage -iwithprefix/bt/esp_ble_mesh/btc/include -iwithprefix/bt/esp_ble_mesh/models/common/include -iwithprefix/bt/esp_ble_mesh/models/client/include -iwithprefix/bt/esp_ble_mesh/models/server/include -iwithprefix/bt/esp_ble_mesh/api/core/include -iwithprefix/bt/esp_ble_mesh/api/models/include -iwithprefix/bt/esp_ble_mesh/api -iwithprefix/bt/esp_ble_mesh/lib/include -iwithprefix/bt/esp_ble_mesh/v1.1/api/core/include -iwithprefix/bt/esp_ble_mesh/v1.1/api/models/include -iwithprefix/bt/esp_ble_mesh/v1.1/btc/include -iwithprefix/bt/porting/ext/tinycrypt/include -iwithprefix/esp_wifi/include -iwithprefix/esp_wifi/include/local -iwithprefix/esp_wifi/wifi_apps/include -iwithprefix/esp_wifi/wifi_apps/nan_app/include -iwithprefix/esp_phy/include -iwithprefix/esp_phy/esp32/include -iwithprefix/esp_netif/include -iwithprefix/mbedtls/port/include -iwithprefix/mbedtls/mbedtls/include -iwithprefix/mbedtls/mbedtls/library -iwithprefix/mbedtls/esp_crt_bundle/include -iwithprefix/mbedtls/mbedtls/3rdparty/everest/include -iwithprefix/mbedtls/mbedtls/3rdparty/p256-m -iwithprefix/mbedtls/mbedtls/3rdparty/p256-m/p256-m -iwithprefix/fatfs/diskio -iwithprefix/fatfs/src -iwithprefix/fatfs/vfs -iwithprefix/wear_levelling/include -iwithprefix/esp_partition/include -iwithprefix/app_update/include -iwithprefix/bootloader_support/include -iwithprefix/bootloader_support/bootloader_flash/include -iwithprefix/esp_app_format/include -iwithprefix/esp_bootloader_format/include -iwithprefix/console -iwithprefix/esp_vfs_console/include -iwithprefix/openthread/include -iwithprefix/openthread/openthread/include -iwithprefix/nvs_flash/include -iwithprefix/spi_flash/include -iwithprefix/espressif__esp_secure_cert_mgr/include -iwithprefix/efuse/include -iwithprefix/efuse/esp32/include -iwithprefix/espressif__json_parser/include -iwithprefix/espressif__jsmn/include -iwithprefix/spiffs/include -iwithprefix/esp_http_client/include -iwithprefix/espressif__json_generator/include -iwithprefix/json/cJSON -iwithprefix/espressif__mdns/include -iwithprefix/espressif__esp_delta_ota/include -iwithprefix/espressif__esp_encrypted_img/include -iwithprefix/espressif__esp_insights/include -iwithprefix/espressif__esp_diagnostics/include -iwithprefix/esp_mm/include -iwithprefix/esp_security/include -iwithprefix/pthread/include -iwithprefix/app_trace/include -iwithprefix/wpa_supplicant/include -iwithprefix/wpa_supplicant/port/include -iwithprefix/wpa_supplicant/esp_supplicant/include -iwithprefix/esp_coex/include -iwithprefix/unity/include -iwithprefix/unity/unity/src -iwithprefix/cmock/CMock/src -iwithprefix/http_parser -iwithprefix/esp-tls -iwithprefix/esp-tls/esp-tls-crypto -iwithprefix/esp_adc/include -iwithprefix/esp_adc/interface -iwithprefix/esp_adc/esp32/include -iwithprefix/esp_adc/deprecated/include -iwithprefix/esp_driver_isp/include -iwithprefix/esp_driver_cam/include -iwithprefix/esp_driver_cam/interface -iwithprefix/esp_driver_jpeg/include -iwithprefix/esp_driver_ppa/include -iwithprefix/esp_gdbstub/include -iwithprefix/esp_hid/include -iwithprefix/tcp_transport/include -iwithprefix/esp_http_server/include -iwithprefix/esp_https_ota/include -iwithprefix/esp_https_server/include -iwithprefix/esp_psram/include -iwithprefix/esp_lcd/include -iwithprefix/esp_lcd/interface -iwithprefix/protobuf-c/protobuf-c -iwithprefix/protocomm/include/common -iwithprefix/protocomm/include/security -iwithprefix/protocomm/include/transports -iwithprefix/protocomm/include/crypto/srp6a -iwithprefix/protocomm/proto-c -iwithprefix/esp_local_ctrl/include -iwithprefix/espcoredump/include -iwithprefix/espcoredump/include/port/xtensa -iwithprefix/idf_test/include -iwithprefix/idf_test/include/esp32 -iwithprefix/ieee802154/include -iwithprefix/mqtt/esp-mqtt/include -iwithprefix/nvs_sec_provider/include -iwithprefix/perfmon/include -iwithprefix/rt/include -iwithprefix/ulp/ulp_common/include -iwithprefix/ulp/ulp_fsm/include -iwithprefix/ulp/ulp_fsm/include/esp32 -iwithprefix/wifi_provisioning/include -iwithprefix/espressif__esp-nn/include -iwithprefix/espressif__esp-nn/src/common -iwithprefix/espressif__rmaker_common/include -iwithprefix/espressif__cbor/port/include -iwithprefix/espressif__esp_diag_data_store/src/rtc_store -iwithprefix/espressif__esp_diag_data_store/include -iwithprefix/espressif__esp-serial-flasher/include -iwithprefix/espressif__esp-serial-flasher/port -iwithprefix/espressif__esp_rcp_update/include -iwithprefix/chmorgan__esp-libhelix-mp3/libhelix-mp3/pub -iwithprefix/espressif__esp-modbus/freemodbus/common/include -iwithprefix/espressif__esp-zboss-lib/include -iwithprefix/espressif__esp-zigbee-lib/include -iwithprefix/espressif__esp-zigbee-lib/include/radio_spinel -iwithprefix/espressif__libsodium/libsodium/src/libsodium/include -iwithprefix/espressif__libsodium/port_include -iwithprefix/espressif__esp-dsp/modules/dotprod/include -iwithprefix/espressif__esp-dsp/modules/support/include -iwithprefix/espressif__esp-dsp/modules/support/mem/include -iwithprefix/espressif__esp-dsp/modules/windows/include -iwithprefix/espressif__esp-dsp/modules/windows/hann/include -iwithprefix/espressif__esp-dsp/modules/windows/blackman/include -iwithprefix/espressif__esp-dsp/modules/windows/blackman_harris/include -iwithprefix/espressif__esp-dsp/modules/windows/blackman_nuttall/include -iwithprefix/espressif__esp-dsp/modules/windows/nuttall/include -iwithprefix/espressif__esp-dsp/modules/windows/flat_top/include -iwithprefix/espressif__esp-dsp/modules/iir/include -iwithprefix/espressif__esp-dsp/modules/fir/include -iwithprefix/espressif__esp-dsp/modules/math/include -iwithprefix/espressif__esp-dsp/modules/math/add/include -iwithprefix/espressif__esp-dsp/modules/math/sub/include -iwithprefix/espressif__esp-dsp/modules/math/mul/include -iwithprefix/espressif__esp-dsp/modules/math/addc/include -iwithprefix/espressif__esp-dsp/modules/math/mulc/include -iwithprefix/espressif__esp-dsp/modules/math/sqrt/include -iwithprefix/espressif__esp-dsp/modules/matrix/mul/include -iwithprefix/espressif__esp-dsp/modules/matrix/add/include -iwithprefix/espressif__esp-dsp/modules/matrix/addc/include -iwithprefix/espressif__esp-dsp/modules/matrix/mulc/include -iwithprefix/espressif__esp-dsp/modules/matrix/sub/include -iwithprefix/espressif__esp-dsp/modules/matrix/include -iwithprefix/espressif__esp-dsp/modules/fft/include -iwithprefix/espressif__esp-dsp/modules/dct/include -iwithprefix/espressif__esp-dsp/modules/conv/include -iwithprefix/espressif__esp-dsp/modules/common/include -iwithprefix/espressif__esp-dsp/modules/matrix/mul/test/include -iwithprefix/espressif__esp-dsp/modules/kalman/ekf/include -iwithprefix/espressif__esp-dsp/modules/kalman/ekf_imu13states/include -iwithprefix/espressif__esp_modem/include -iwithprefix/espressif__esp_schedule/include -iwithprefix/espressif__network_provisioning/include -iwithprefix/espressif__esp_rainmaker/include -iwithprefix/espressif__qrcode/include -iwithprefix/joltwallet__littlefs/include -iwithprefix/fb_gfx/include -DPLATFORMIO=60118 -DARDUINO_ESP32_DEV -DESP32_ARDUINO_LIB_BUILDER -DESP_MDNS_VERSION_NUMBER=\"1.8.2\" -DESP_PLATFORM -DIDF_VER=\"v5.4.1-1-g2f7dcd862a-dirty\" -DMBEDTLS_CONFIG_FILE=\"mbedtls/esp_config.h\" -DMD5_ENABLED=1 -DOPENTHREAD_CONFIG_FILE=\"openthread-core-esp32x-spinel-config.h\" -DOPENTHREAD_PROJECT_LIB_CONFIG_FILE=\"openthread-core-esp32x-spinel-config.h\" -DSERIAL_FLASHER_BOOT_HOLD_TIME_MS=50 -DSERIAL_FLASHER_RESET_HOLD_TIME_MS=100 -DSOC_MMU_PAGE_SIZE=CONFIG_MMU_PAGE_SIZE -DSOC_XTAL_FREQ_MHZ=CONFIG_XTAL_FREQ -DUNITY_INCLUDE_CONFIG_H -D_GLIBCXX_HAVE_POSIX_SEMAPHORE -D_GLIBCXX_USE_POSIX_SEMAPHORE -D_GNU_SOURCE -D_POSIX_READER_WRITER_LOCKS -DTF_LITE_STATIC_MEMORY -DCHIP_CONFIG_SOFTWARE_VERSION_NUMBER=0 -DNDEBUG -DCHIP_MINMDNS_DEFAULT_POLICY=1 -DCHIP_MINMDNS_USE_EPHEMERAL_UNICAST_PORT=0 -DCHIP_MINMDNS_HIGH_VERBOSITY=0 -DCHIP_DNSSD_DEFAULT_MINIMAL=true -DCHIP_DNSSD_DEFAULT_NONE=false -DCHIP_DNSSD_DEFAULT_PLATFORM=false -DARDUINO_ARCH_ESP32 -DCHIP_HAVE_CONFIG_H -DESP32=ESP32 -DF_CPU=240000000L -DARDUINO=10812 -DARDUINO_VARIANT=\"doitESP32devkitV1\" "-DARDUINO_BOARD=\"DOIT ESP32 DEVKIT V1\"" -DARDUINO_PARTITION_default -I.pio/libdeps/esp32doit-devkit-v1/ESPAsyncWebServer/src -IC:/.platformio/packages/framework-arduinoespressif32/libraries/FS/src -I.pio/libdeps/esp32doit-devkit-v1/ArduinoJson/src "-I.pio/libdeps/esp32doit-devkit-v1/Async TCP/src" -IC:/.platformio/packages/framework-arduinoespressif32/libraries/WiFi/src -IC:/.platformio/packages/framework-arduinoespressif32/libraries/Network/src -IC:/.platformio/packages/framework-arduinoespressif32-libs/esp32/dio_qspi/include -IC:/.platformio/packages/framework-arduinoespressif32/cores/esp32 -IC:/.platformio/packages/framework-arduinoespressif32/variants/doitESP32devkitV1 .pio/libdeps/esp32doit-devkit-v1/ESPAsyncWebServer/src/AsyncWebServerRequest.cpp
xtensa-esp32-elf-g++ "@E:\My Drive\OpenHaldex\Can2Cluster\.pio\build\esp32doit-devkit-v1\tmp6vwye_2l.tmp"
Using tempfile E:\My Drive\OpenHaldex\Can2Cluster\.pio\build\esp32doit-devkit-v1\tmpolyusiuc.tmp for command line:
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

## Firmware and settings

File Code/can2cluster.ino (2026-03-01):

/* 
CAN-BUS converter to Digital Output.  Used for MK2/MK3 'analog' clusters in ME7.x and aftermarket conversions and will provide an EML/EPC light.
All outputs are configurable 12v Square Wave with definable max limits based on x RPM / Speed etc.  All outputs are 200mA max(!).  Reverse is MOSFET and 5A max(!).

Main features:
> 12v Positive output for reverse light (5A max!)
> RPM/Speed/EML/EPC outputs (200mA max!)
> DSG Paddles (ground to activate)
> Needle sweep & shift light
> WiFi config.

Forbes-Automotive, 2025
*/

#include "can2cluster_defs.h"

// for CAN
ESP32_CAN<RX_SIZE_256, TX_SIZE_16> chassisCAN;

// for GPS
SoftwareSerial ss(pinRX_GPS, pinTX_GPS);
TinyGPSPlus gps;

// for EEPROM
Preferences pref;

// for inputs / paddles
InterruptButton btnPadUp(pinPaddleUp, LOW, GPIO_MODE_INPUT, 1000, 500, 750, 80000);      // pin, GPIO_MODE_INPUT, state when pressed, long press, autorepeat, double-click, debounce
InterruptButton btnPadDown(pinPaddleDown, LOW, GPIO_MODE_INPUT, 1000, 500, 750, 80000);  // pin, GPIO_MODE_INPUT, state when pressed, long press, autorepeat, double-click, debounce

// define two hardware timers for RPM & Speed outputs
hw_timer_t* timer0 = NULL;
hw_timer_t* timer1 = NULL;

//if (1) {  // This contains all the timers/Hz/Freq. stuff.  Literally in a //(1) to let Arduino IDE code-wrap all this...
// timer for RPM
void IRAM_ATTR onTimer0() {
  rpmTrigger = !rpmTrigger;  // flip-flop to create 50% DC pulse
  if (coilType) {
    digitalWrite(pinCoil, rpmTrigger);  // if 'use coil', trigger the coil
  } else {
    digitalWrite(pinCoil, LOW);        // if NOT 'use coil', so turn off the coil (save power)
    digitalWrite(pinEML, rpmTrigger);  // if NOT 'use coil', trigger the square wave RPM output
  }
}

// timer for Speed
void IRAM_ATTR onTimer1() {
  speedTrigger = !speedTrigger;          // flip-flop to create 50% DC pulse
  digitalWrite(pinSpeed, speedTrigger);  // trigger speed output
}

// setup timers
void setupTimer() {
  timer0 = timerBegin(0, 40, true);  // used to be div 80
  timerAttachInterrupt(timer0, &onTimer0, true);

  timer1 = timerBegin(1, 40, true);  // used to be div 80 - 40 results in perfect hz transmission
  timerAttachInterrupt(timer1, &onTimer1, true);
}
//}

void setup() {
  basicInit();   // basic init for setting up Serial / IO / CAN / GPS
  setupTimer();  // setup the timers (with a base frequency)
  setupTasks();  // setup tasks for each of the main functions - CAN Chassis/Haldex handling, Serial prints, Standalone, etc - in '_io.ino'

  if (hasNeedleSweep) {
    needleSweep();  // carry out needle sweep if defined
  }

  connectWifi();         // enable / start WiFi
  WiFi.setSleep(false);  // for the ESP32: turn off sleeping to increase UI responsivness (at the cost of power use)
  setupUI();             // setup wifi user interface
  //setupOTA();            // setup OTA update server - in '_OTA.ino'
}

void loop() {
  if (selfTest) {
    diagTest();  // purely for bench debugging
  }

  if (tempNeedleSweep) {  // only here if tested in WiFi
    needleSweep();
    tempNeedleSweep = false;  // reset the flag
  }

  if (tempShiftLight) {                                                                // only here if tested in WiFi
    blinkLED(shiftLightRate, shiftFlashes, useEPCShiftLight, useEMLShiftLight, 0, 0);  // args: flash rate, number of flashes, use EPC or use EML as light, RPM/Speed are set to 0, don't use them (kept in for self-test)
    tempShiftLight = false;                                                            // reset the flag
#if serialDebugIO
    DEBUG("tempShiftLight");
#endif
  }

  // check to see what the current RPM is, if it's over the limit, trigger the EPC or EML light as a warning!
  if (useEPCShiftLight || useEMLShiftLight) {
    if (vehicleRPM > shiftLimit) {
      blinkLED(shiftLightRate, shiftFlashes, useEPCShiftLight, useEMLShiftLight, 0, 0);  // args: flash rate, number of flashes, use EPC or use EML as light, RPM/Speed are set to 0, don't use them (kept in for self-test)
    }
  }

  // set EML, EPC & Reverse outputs
  testEML ? digitalWrite(pinEML, HIGH) : digitalWrite(pinEML, vehicleEML);
  testEPC ? digitalWrite(pinEPC, HIGH) : digitalWrite(pinEPC, vehicleEPC);
  testReverse ? digitalWrite(pinReverse, HIGH) : digitalWrite(pinReverse, vehicleReverse);

  delay(10);
}

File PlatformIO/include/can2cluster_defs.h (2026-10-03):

#ifndef CAN2CLUSTER_DEFS_H
#define CAN2CLUSTER_DEFS_H

#include <Arduino.h>
#include <stdio.h>
#include <stdlib.h>
#include "freertos/FreeRTOS.h"
#include "freertos/task.h"
#include "freertos/semphr.h"

#include <TinyGPSPlus.h> // included for GPS
#include <driver/twai.h>  // TWAI (CAN) for ESP32
#include <Preferences.h>    // for eeprom/remember settings
#include <WiFi.h>           // included for WiFi pages
#include <ESPmDNS.h>        // included for WiFi pages
#include <OneButton.h>

// V3.24 - OTA overhaul: shared ota_manager/wifi_manager v2 + data/ota.js
//         (guided GitHub update, Home WiFi bridge mode, recovery page).
#define FW_VERSION "3.24"

#define COOLANT_CAL_MAX 12 // max calibration points for the coolant temp gauge
// Coolant gauge PWM (the only LEDC output left; speed/RPM are GPTimer square
// waves). LEDC 10-bit at the 80 MHz APB clock tops out at 80e6/1024 ≈ 78125 Hz.
#define COOLANT_PWM_FREQ_MAX 78000

/* Defines */
// Debug statements
#define serialDebug 0        // if 1, will use Serial talkback ** CAN CHANGE THIS **
#define ChassisCANDebug 0    // if 1, will print CAN 2 (Chassis) messages ** CAN CHANGE THIS **
#define serialDebugWifi 0    // for wifi feedback
#define serialDebugEEP 0     // for EEP Serial feedback
#define serialDebugGPS 0     // for GPS Serial feedback
#define serialDebugPaddles 0 // for Paddle Serial feedback
#define serialDebugDSG 0     // for DSG Serial feedback
#define serialDebugIO 0      // for General IO Serial feedback
#define serialDebugCAN 0     // for CAN/TWAI driver Serial feedback
#define serialDebugI2C 0     // for I2C (board/MCP4725/TCA9554) Serial feedback
#define detailedDebugStack 0 // for showing stack usage of each task (in showState() task)

#define serialMonitorRefresh 1000 // serial monitor feedback in ms
#define eepRefresh 5000           // EEPROM save in ms
#define labelRefresh 200          // wifi label refresh in ms
#define broadcastSpeedRefresh 20  // speed sending via. CAN in ms
#define broadcastGRARefresh 10    // paddle task period in ms: the shifter 0x0AF frame is 10 ms; GRA/0x3DD/0x128 go out on alternate ticks (20 ms)
#define gearPause 20              // vTaskDelay (in _dsg.ino) for DSG refreshes
#define rpmPause 50               // vTaskDelay for the RPM & Speed output tasks (50 ms = 20 Hz). The output frequency only changes on a real value change, so a faster loop just burns CPU and bogs down the other core-1 tasks.

// DSG speed smoothing: gear and RPM arrive on separate CAN frames, so during a
// shift they are momentarily inconsistent and the calculated speed spikes/bucks.
#define dsgGearSettleMs 300       // hold last DSG speed for this long after a gear change (real road speed barely moves during a shift)
#define dsgSpeedSmoothing 0.35    // low-pass factor 0..1 (1 = no smoothing) applied to DSG speed to remove residual RPM jitter

// global object declarations
extern HardwareSerial ss; // UART2 for GPS (NEO-6M)
extern TinyGPSPlus gps;
extern Preferences pref;
extern OneButton btnPadUp;
extern OneButton btnPadDown;

// setup - main inputs
#define mphFactor 621371              // to convert from kmh > mph (multiply, then /1000000)
#define wifiHostName "Can2Cluster" // the WiFi name

// setup - tweaky things
#define shiftLightRate 100 // flash EPC at xx ms.  Decreasing may lead to a 'constant' light because of the human eye... ** CAN CHANGE THIS **
#define durationReset 1500 // ms with no pulse before Hall/RPM input is considered stale and reset to 0

// setup - cluster RPM & speed limits
extern uint16_t clusterRPMLimit; // rpm limit of the cluster face
extern uint16_t shiftLimit;      // shift limit (for shift light)
extern uint8_t shiftFlashes;     // number of flashes for shift light
extern uint8_t sweepSpeed;       // for needle sweep rate of change (in ms)
extern uint16_t maxSpeed;        // maximum cluster speed in kmh on the cluster
extern uint16_t maxRPM;          // maximum rpm in hz for the cluster
extern uint16_t maxFreqHall;     // max frequency for top speed using the 02J / 02M hall sensor
extern uint16_t maxFreqVR;       // max frequency for top speed using a variable-reluctance (VR) sensor
extern bool useEPCShiftLight;    // bool to use the EPC as a shift light
extern bool useEMLShiftLight;    // bool to use the EML as a shift light

// setup - step changes (for needle sweep)
extern uint16_t stepRPM;
extern uint16_t stepSpeed;
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

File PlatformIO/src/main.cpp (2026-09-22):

/* 
CAN-BUS converter to Digital Output.  Used for MK2/MK3 'analog' clusters in ME7.x and aftermarket conversions and will provide an EML/EPC light.
All outputs are configurable 12v Square Wave with definable max limits based on x RPM / Speed etc.  All outputs are 200mA max(!).  Reverse is MOSFET and 5A max(!).

Main features:
> 12v Positive output for reverse light (5A max!)
> RPM/Speed/EML/EPC outputs (200mA max!)
> GPS input for speedo and odometer (1Hz or 5Hz update)
> DSG Paddles (ground to activate)
> Needle sweep & shift light
> WiFi config
> SavvyCAN / GVRET implementation for CAN analysis (TCP:23 or Serial 1Mbaud)
> DSG / TP2.0 & UDS Support

Forbes-Automotive, 2025
*/

#include "can2cluster_defs.h"
#include "can2cluster_gps.h"
#include "can2cluster_io.h"
#include "can2cluster_savvycan.h"
#include "power_manager.h"
#include "wifi_manager.h"

// for GPS
HardwareSerial ss(2); // UART2 for GPS (NEO-6M)
TinyGPSPlus gps;

// for EEPROM
Preferences pref;

// for inputs / paddles
OneButton btnPadUp(pinPaddleUp, true, true);     // active-low with internal pull-up
OneButton btnPadDown(pinPaddleDown, true, true); // active-low with internal pull-up

void setup() {
  basicInit();   // basic init for setting up Serial / IO / CAN / GPS
  setupTasks();  // setup tasks for each of the main functions - CAN Chassis/Haldex handling, Serial prints, Standalone, etc - in '_io.ino'

  if (hasNeedleSweep) {
    tasksSuspendAll();
    needleSweep();
    tasksResumeAll();
  }

  connectWifi();         // enable / start WiFi
  setupUI();             // setup wifi user interface
  setupAnalyzer();       // SavvyCAN/GVRET analyzer (TCP:23 or Serial 1Mbaud)

  // Universal reduced-power module: turns WiFi off 5 min after the last client
  // disconnects, scales the CPU 240->80 MHz, releases Bluetooth and kills the
  // onboard LED to cut current draw (and therefore linear-regulator heat).
  power_config_t pcfg = powerDefaultConfig();
  pcfg.verbose = serialDebugWifi; // honour the project's WiFi debug gating
  powerInit(&pcfg);
}

void loop() {
  // Apply GPS rate from EEPROM after satellite lock (flagged by parseGPS).
  // Tasks are suspended for the duration so the delay() calls inside
  // setGPSUpdateRate() are not disrupted by higher-priority core-1 tasks.
  // The API path doesn't need this because AsyncTCP callbacks run on core 0.
  if (gpsAutoRateApplyPending())
  {
    tasksSuspendAll();
    String resp;
    bool ok = setGPSUpdateRate(gpsUpdateRateHz, resp);
    tasksResumeAll();
    DEBUG_GPS("[Auto] Rate apply %s: %s", ok ? "OK" : "FAILED", resp.c_str());
  }

  updateButtons();

  if (tempNeedleSweep) {
    tasksSuspendAll();
    needleSweep();
    tasksResumeAll();
    tempNeedleSweep = false;
  }

  wifiManagerTick(); // Home WiFi (bridge mode): connection tracking + retry back-off

  delay(10);
}

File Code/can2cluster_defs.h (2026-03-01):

#include <stdio.h>
#include <stdlib.h>
#include "freertos/FreeRTOS.h"
#include "freertos/task.h"
#include "freertos/semphr.h"

#include <TinyGPSPlus.h>     // included for GPS
#include <SoftwareSerial.h>  // included for GPS
#include <ESP32_CAN.h>       // included for CAN
#include <Preferences.h>     // for eeprom/remember settings
#include <ESPUI.h>           // included for WiFi pages
#include <WiFi.h>            // included for WiFi pages
#include <ESPmDNS.h>         // included for WiFi pages
#include "InterruptButton.h"

/* Defines */
// Debug statements
#define serialDebug 1         // if 1, will use Serial talkback ** CAN CHANGE THIS **
#define ChassisCANDebug 0     // if 1, will print CAN 2 (Chassis) messages ** CAN CHANGE THIS **
#define serialDebugWifi 0     // for wifi feedback
#define serialDebugEEP 0      // for EEP Serial feedback
#define serialDebugGPS 1      // for GPS Serial feedback
#define serialDebugPaddles 0  // for Paddle Serial feedback
#define serialDebugDSG 0      // for DSG Serial feedback
#define serialDebugIO 0       // for General IO Serial feedback
#define detailedDebugStack 0

#define serialMonitorRefresh 1000  // serial monitor feedback in ms
#define eepRefresh 2000            // EEPROM save in ms
#define labelRefresh 200           // wifi label refresh in ms
#define broadcastSpeedRefresh 20   // speed sending via. CAN in ms
#define broadcastGRARefresh 20     // paddle (GRA) sending via. CAN in ms
#define gearPause 20               // vTaskDelay (in _dsg.ino) for DSG refreshes
#define rpmPause 5                 // vTaskDelay (in _io.ino) for RPM & Speed refreshes

// setup - main inputs
#define speedUnits 0                   // 0 = kph, 1 = mph
#define mphFactor 621371               // to convert from kmh > mph
#define wifiHostName "Can2Cluster V2"  // the WiFi name

// setup - tweaky things
#define shiftLightRate 60  // flash EPC at xx ms.  Decreasing may lead to a 'constant' light because of the human eye... ** CAN CHANGE THIS **

// setup - cluster RPM & speed limits
extern uint16_t clusterRPMLimit = 7000;  // rpm limit of the cluster face
extern uint16_t shiftLimit = 6000;       // shift limit (for shift light)
extern uint8_t shiftFlashes = 3;         // number of flashes for shift light
extern uint8_t sweepSpeed = 18;          // for needle sweep rate of change (in ms)
extern uint16_t maxSpeed = 200;          // maximum cluster speed in kmh on the cluster
extern uint16_t maxRPM = 230;            // maximum rpm in hz for the cluster
extern uint16_t maxFreqHall = 200;       // max frequency for top speed using the 02J / 02M hall sensor
extern bool useEPCShiftLight = false;    // bool to use the EPC as a shift light
extern bool useEMLShiftLight = false;    // bool to use the EML as a shift light

// setup - step changes (for needle sweep)
extern uint16_t stepRPM = 120;
extern uint16_t stepSpeed = 100;

// setup - pins (output)
#define pinRX_CAN 17   // pin output for SN65HVD230 (CAN_RX)
#define pinTX_CAN 16   // pin output for SN65HVD230 (CAN_TX)
#define pinRX_GPS 14   // pin output for GPS NEO6M (GPS_RX)
#define pinTX_GPS 13   // pin output for GPS NEO6M (GPS_TX)
#define pinCoil 18     // pin output for RPM (MK2/High Output Coil Trigger)
#define pinEPC 19      // pin output for EPC
#define pinEML 21      // pin output for EML
#define pinRPM 22      // pin output for RPM
#define pinSpeed 23    // pin output for Speed
#define onboardLED 2   // pin onboard LED
#define pinReverse 26  // pin output for reverse mosfet

// setup - pins (inputs)
#define pinPaddleUp 34    // pin input for DSG paddle up
#define pinPaddleDown 35  // pin input for DSG paddle down
#define pinHallSensor 25  // pin input for Hall Sensor

// Baud Rates
#define baudSerial 115200  // baud rate for debug
#define baudGPS 9600       // baud rate for the GPS device
#define baudCAN 500000     // baud rate for CAN

// DSG variables
#define PI 3.141592653589793
#define LEVER_P 0x8               // park position
#define LEVER_R 0x7               // reverse position
#define LEVER_N 0x6               // neutral position
#define LEVER_D 0x5               // drive position
#define LEVER_S 0xC               // spot position
#define LEVER_TIPTRONIC_ON 0xE    // tiptronic active
#define LEVER_TIPTRONIC_UP 0xA    // tiptronic up
#define LEVER_TIPTRONIC_DOWN 0xB  // tiptronic down

#ifdef serialDebug
#define DEBUG(x, ...) Serial.printf(x "\n", ##__VA_ARGS__)
#define DEBUG_(x, ...) Serial.printf(x, ##__VA_ARGS__)
#else
#define DEBUG(x, ...)
#define DEBUG_(x, ...)
#endif
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

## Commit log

2025-01-17 V1.02
    Gerbers ordered
    [FISCuntrol Board2-CAN.brd, FISCuntrol Board2-CAN.sch]
2025-03-01 V1.03
    Revised.
    [Pinouts 2.xlsx]
2025-03-27 V1.07
    Calibrated PWM motor
2025-03-27 V1.08
    Revised buttons
2025-07-24 Enclosure
    Added
    [Can2Cluster.STL, Can2ClusterLid.STL]
2025-08-14 Module Pinouts
    Module pinouts
    [Module Pinouts.xlsx, Pinouts 2.xlsx]
2025-08-14 Update Module Pinouts.xlsx
    [Module Pinouts.xlsx]
2025-08-17 V1.11
    Refresh
    [Module Pinouts.xlsx]
2025-09-02 V1.08 - DSG Reverse
    V1.08 - added DSG specifics
    [can2cluster.ino, can2cluster_can.ino, can2cluster_defs.h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]
2025-09-04 Added enclosures
    [Can2ClusterV2.STL, Can2ClusterV2LidGPS.STL, Can2ClusterV2LidNoGPS.STL]
2025-10-26 V1.13
    V1.13 - added DSG Up/Down paddles & DSG gear logging
2025-10-30 V1.14
    V1.14 - changed button library to ESP32 Interrupt Button to make paddles faster
2025-12-05 V1.17
    Corrected EEP last values
    [can2cluster_eep.ino, can2cluster_io.ino, can2cluster_wifi.ino]
2026-01-29 Added board connector
2026-02-17 Latest, missed a var
    [can2cluster_wifi.ino]
2026-03-01 V1.18
    Added error on GPS wiring
    [can2cluster.ino, can2cluster_can.ino, can2cluster_defs.h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]
2026-03-13 Releases
    added
    [partitions.csv]
2026-04-07 Pinout (Mini)
    Added Mini pinout
    [Module Pinouts.xlsx]
2026-05-30 V3.00
    Added UDS/TP2.0, Speed/RPM Hall improvements, needle sweep
2026-06-23 V3.10
    Added power management
2026-08-20 V3.20
    Added in MQB RPM, DSG Park/Reverse + Paddles (from Matt's log!).
    [app.js, can2cluster_can.cpp, can2cluster_defs.cpp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]
2026-09-29 V3.24
    DSG Log attached.
2026-10-27 Fuel Pump activation
    Added a fuel pump trigger, just like DSG Park.
